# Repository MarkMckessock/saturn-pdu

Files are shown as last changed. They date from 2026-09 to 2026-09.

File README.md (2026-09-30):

# saturn-pdu

**A 1U rack PDU delivering six independently switched and metered 19V outputs,
for a six-node Minisforum MS-01 Kubernetes cluster.**

> **Status: draft specification. Nothing here has been built or bench-verified.**
> Every figure is analytical. Do not fabricate from this repository yet.

Derived from [Shrike-Lab/HomeLab-PDU-V1](https://github.com/Shrike-Lab/HomeLab-PDU-V1).
Licensed **CERN-OHL-S v2** (strongly reciprocal) -- see [`LICENSE`](LICENSE) and
[`NOTICE`](NOTICE).

---

## The problem

Six MS-01 nodes, six 180W bricks, six mains outlets, twelve cables, and no way
to see what any node draws or to power-cycle a wedged one without walking to the
rack.

## What this is

One 1U box: a single mains inlet, six 19V outputs, each switchable over the
network and each reporting volts, amps and watts.

```
IEC inlet ──► RSP-1000-48 ──► 48V bus ─┬──► [2ch board A] ──► ports 1,2
                  ▲                     ├──► [2ch board B] ──► ports 3,4
           remote ON/OFF                └──► [2ch board C] ──► ports 5,6
           (front button)                          │
                                          [control board]
                                          ESP32-S3 + wired Ethernet
                                          6x INA226 telemetry
                                          Prometheus /metrics
```

Each channel is an LM5116 synchronous buck, 48V down to 19V at 7A, with its own
fuse, its own current limit, and its own overvoltage crowbar that works **with
the microcontroller unpowered**.

## Three design rules that explain most of the decisions

1. **Outputs fail ON.** Channels are held on by resistors. The MCU can only turn
   one *off*, by actively pulling a pin down. An MCU that is crashed,
   unprogrammed, unpowered or physically removed leaves every node running.
   No firmware path may ever de-energise an output autonomously.
2. **Protection does not depend on software.** A shorted high-side transistor
   puts 48V on a 19V input and destroys a node. Disabling its controller
   achieves nothing when the transistor is a short, so each output carries an
   SCR crowbar with its own reference, powered from its own output.
3. **The display cannot break anything.** It is a separate device on a UART
   link, not the controller. Unplug it and all six outputs keep running and stay
   controllable over the network. A single tap can never de-energise a node.

## Honest cost comparison

About **$750-830** in parts, realistically **$900-1,100** for a first unit once
you budget the three board spins a first high-current layout needs. Six stock
bricks are $240-360.

A used switched-and-metered rack PDU (APC AP7921 class, $150-300) plugged into
your existing bricks gives you remote switching and per-outlet metering this
afternoon. **What this project buys over that is the 1U consolidation and the
elimination of six bricks -- a space and elegance goal, not a functional one.**
That is a fine reason to build it. It should just be the actual reason.

## Safety

**Read [`docs/safety.md`](docs/safety.md) before building or operating.**

The short version: the 19V outputs cannot shock you (IEC 62368-1 ES1), but a
live barrel plug dropped on a rack rail will melt itself. Unused ports stay off;
switch a port off before unplugging it. The mains side inside the chassis *can*
kill you -- unplug at the wall before opening the lid, and wait a minute.

## Repository layout

| Path | Contents |
|---|---|
| `params.yaml` | **Single source of truth.** Every dimension, rating and threshold used in more than one place. Docs, firmware and CAD all read from it |
| `docs/` | Specification, power budget, thermal, protection/FMEA, safety, upstream analysis, deviation log |
| `hardware/kicad/` | KiCad projects: 2-channel power board, control board, backplane |
| `cad/` | Parametric FreeCAD Python, plus STEP/STL exports |
| `firmware/` | ESPHome configuration for the control board and the display |
| `fab/` | Gerbers, BOM, pick-and-place |
| `reference/upstream-19in/` | Upstream's 19" B-rep solids, kept as dimensional reference |

## Build order

Stage-gated. **Do not order the full board set before stage 4 passes.**

| # | Stage | Gate |
|---|---|---|
| 0 | Measure the barrel jack and the real six-node draw | Both recorded |
| 1-2 | Schematics, BOM and sourcing | No unsourceable parts |
| 3 | LM5116 evaluation board, built and measured | A known-good reference exists |
| 4 | One 2-channel board: bring-up, fault injection, 72h burn-in, fault injection **again** | **Hard gate** |
| 5-6 | Control board, firmware, display, chassis | Fail-ON verified by pulling the MCU |
| 7 | **30-day canary on one worker node** | **Hard gate.** Any event resets to day zero |
| 8 | Remaining five nodes; control-plane nodes last | 24h six-node soak |

Full detail in [`docs/SPECIFICATION.md`](docs/SPECIFICATION.md) sections 8 and 9.

## Open items

Two measurements and one accepted risk. Both measurements carry provisional
values in `params.yaml` and neither blocks design work.

| ID | Item | Why it does not block |
|---|---|---|
| OPEN-5 | Barrel jack dimensions | Both candidate sizes share the same 8mm panel thread, so the panel cutout is identical. Only the part number is provisional |
| OPEN-6 | Real six-node peak draw | **Downgraded to informational.** The fitted RSP-1000-48 absorbs a reading 38% above estimate, so this validates the power budget rather than gating a purchase |
| R-0 | No independent design review | **Accepted, not resolved.** Bench testing and the 30-day canary stand in for it. Residual risk is moderate and knowingly taken |

## Contributing

This is a personal homelab project, not a product. Issues and observations are
welcome -- particularly from anyone with power-electronics experience, given
R-0. Pull requests are not expected.

Derivatives must remain under CERN-OHL-S v2 and must publish editable source,
not only exports. Upstream's source is in its git history; this repository keeps it in the tree.

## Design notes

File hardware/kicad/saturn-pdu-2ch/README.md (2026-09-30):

# saturn-pdu-2ch — 2-channel power board

Open `saturn-pdu-2ch.kicad_pro` in KiCad 10.

| File | What it is | Made by |
|---|---|---|
| `saturn-pdu-2ch.kicad_sch`, `channel.kicad_sch` | Schematic. Top sheet + one channel sheet used twice (CH1, CH2) | `tools/gen_2ch_sch.py` (WP-4b) |
| `saturn-pdu-2ch.kicad_pcb` | Board: outline, holes, stackup, rules, every part loaded and linked | `tools/setup_2ch_pcb.py` (WP-4c) |
| `saturn-pdu-2ch.kicad_dru` | Custom design rules (48 V spacing, switch-node keep-away) | `tools/setup_2ch_pcb.py` |

**Both generator scripts are one-shot.** They overwrite their output. After any hand
edit, change the board from the schematic with *Tools → Update PCB from Schematic*
(F8), never by re-running a script.

## State at the end of WP-4c

- ERC: 0 errors, 0 warnings.
- DRC with schematic parity: **0 parity issues, no errors other than unrouted
  connections.** The remaining warnings are silkscreen labels overlapping each other,
  which go away as parts are spread out.
- Board: 90 × 130 mm, 2 mm corner radius (upstream's outline), 4 × M3 holes 4 mm in from
  each corner.
- Stackup: 4 layers, 2 oz outer / 1 oz inner, 1.62 mm, ENIG. The dielectric split is
  nominal — swap in the fab's own 2 oz stackup when ordering.
- In1.Cu has a full GND plane (press **B** to fill it). In2.Cu is free.

### Net classes

| Class | Nets | Track | Clearance |
|---|---|---|---|
| HV | +48V, VIN_F, SW, HB, HO, HO_G, SNUB | 1.0 mm | 0.2 mm (0.5 mm to non-HV copper, except pad-to-pad inside a part) |
| POWER | VOUT_REG, VOUT1/2, ISNS, GND | 2.0 mm | 0.2 mm |
| GATE | LO, LO_G | 0.5 mm | 0.2 mm |
| Default | everything else | 0.2 mm | 0.2 mm |

The track widths are only defaults. **Carry the 7 A paths in copper pours, not tracks.**

## Placement is a starting point, not a layout

Parts are packed in two columns, one per channel. Power flows from top (J1, 48 V in) to
bottom (J2, 19 V out). Each channel is a KiCad group, so it moves as one.

The order inside a column is roughly right, but the spacing is not. Do the layout
(WP-4d) with **TI's LM5116 EVM layout open beside it** (R-0 control 1). Put every place
you depart from it in `docs/deviations.md`.

## Layout checklist, most important first

1. **Hot loop as small as possible.** Input ceramics (C103–C106) → high-side FET (Q101) →
   low-side FET (Q102) → sense resistor (R103) → back to the ceramics' ground. Keep them
   side by side on the top layer, with the In1 GND plane directly underneath. This loop's
   size sets the switch-node spike, and the D-10 bench gate requires that spike to stay
   at or below 54 V.
2. **Keep the switch node (SW) small.** It only needs to join the FETs and L101. Don't
   pour extra copper on it. Keep it away from FB, CS, OVP_REF and I²C (a DRC rule
   enforces 1 mm).
3. **Kelvin sense.** CS and CSG are 0 Ω links (R104, R105). Route them as a close pair
   straight to R103's pads, not onto the power copper. Do the same for the INA226 inputs
   (VOUT_REG and VOUT) at R118's pads.
4. **Gate drive.** Run HO next to SW and LO next to GND, both short, from U101 to the
   FETs.
5. **Analog ground.** The LM5116 exposed pad is the star point. Place the FB divider
   (R112/R113), the compensation parts (R114, C118, C119) and the RT, SS, RAMP and VCC
   parts next to U101, grounded to its pad area rather than to the power path.
6. **Heat.** Put a thermal-via array under both FETs, into the In1 plane. The inductor,
   R103, R118 and R119 all need copper to spread heat into.
7. **Crowbar.** The SCR (Q105) goes near J2, across VOUT with short, wide copper. The
   OVP divider (R120/R121) senses at the output, not at the inductor.
8. **Snubber (R106/C108, not fitted).** Place it hard across Q102's drain and source so
   it works if it is ever needed.
9. **Connectors.** Pour +48V from J1 to both fuses. Run each VOUT to J2 pins as a pour
   and use both pins.

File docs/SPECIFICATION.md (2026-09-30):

# Saturn PDU — Design Specification v0.1 (DRAFT, pre-review)

**Project:** 1U rack PDU delivering six independently switched and metered 19V outputs
for a six-node Minisforum MS-01 Kubernetes cluster.
**Derived from:** [Shrike-Lab/HomeLab-PDU-V1](https://github.com/Shrike-Lab/HomeLab-PDU-V1) (CERN-OHL-S v2)
**Status:** Draft for review. **Nothing here has been built or bench-verified.**
All calculations are analytical and must be confirmed against manufacturer datasheets
and on hardware before fabrication. Sections marked **[OPEN]** are unresolved.

---

## 1. Context and scope

### 1.1 Problem

Six MS-01 nodes each ship with a 180W 19V external brick. That is six bricks, six mains
outlets, twelve cables and no visibility into per-node power. There is no way to power
cycle a wedged node without physical access to the rack.

### 1.2 Goal

One 1U unit: single mains inlet, six 19V outputs, each independently switchable over the
network and each metered for voltage, current and power.

### 1.3 Out of scope

- Mains-side redundancy, UPS or ATS functions
- Genuine N+1 output redundancy (see §4.2.4 — explicitly rejected)
- Powering anything other than 19V DC loads
- Prometheus/Grafana/Gatus integration on the Saturn side (follow-on, §10)

### 1.4 Relationship to upstream

Upstream is a 5× 65W USB-C PD distribution board fed from a 300W/24V supply. Two facts
determine how much can be inherited:

1. **The load is incompatible.** The MS-01 takes 19V via a barrel jack and
   [cannot be powered over USB-C](https://www.galaxus.at/en/s1/questionandanswer/hello-can-the-mini-pc-also-be-supplied-with-power-via-usb-c-or-is-it-only-possible-with-the-mains-ad-782803);
   Minisforum support confirms the barrel jack is required. Every USB-C PD module, the
   PD-specific board and the 24V rail are discarded.
2. **Upstream's editable source exists only in its git history.** _Corrected at WP-4c:_
   the original census checked only the current tree and wrongly concluded the originals
   were withheld. The KiCad project and SolidWorks parts were committed in December 2025
   and removed from the tree in February 2026; they remain in history under CERN-OHL-S
   (docs/upstream-analysis.md §1).

This is therefore a **new design that inherits upstream's mechanical architecture and
protection patterns**, not a modification of upstream's electronics. See §2.

---

## 2. Upstream analysis (reverse-engineered from fab files)

### 2.1 What was extracted

| Property | Value | Source |
|---|---|---|
| Board outline | **90 × 130 mm** (X 51.8→141.8, Y −38.3→−168.3) | `Edge_Cuts.gm1` |
| Stackup | 2-layer, 1.6mm, 2oz | README; confirmed by pour-heavy layout |
| Trace apertures | 0.8 / 1.0 / **2.0 mm max** | `F_Cu.gtl` aperture list |
| Copper pours | 17 regions top, 1 bottom (GND plane) | `G36` region count |
| Drills | 0.6 / 0.75 / 1.0 / 1.8 / 3.2 mm PTH; 3.0 mm NPTH ×4 — **connector pegs, not mounting holes** (corrected at WP-4c) | `.drl` tool tables |

### 2.2 Reconstructed topology

Through-hole connectivity is fully recoverable from `HomeLab-PSU-V1_netlist.ipc`:

```
J1 (Molex Mini-Fit Jr) +24V ─► F1 15A ─► Q1 high-side P-FET ─► +24V_SWITCHED
                                          ▲ gate: R4 100k, D7 12V zener,
                                            R2 47k, R3 100R, latched from J2 button
        D6 SMCJ26A bulk TVS, C1/C2 470µF
                                             │
        ┌────────────┬────────────┬──────────┴─┬────────────┐
     F2 3A        F3 3A        F4 3A        F5 3A        F6 3A
        │            │            │            │            │
     J3/J8       J4/J9      J5/J10      J6/J11      J7/J12    ◄── XPM52C PD modules
     + D1–D5 SMBJ26A TVS, C5–C9 470µF, C10–C14 1µF, C15–C19 100nF
                                             │
                              J13 ─► buck module ─► J15/J16 ─► J17/J18 fan headers
```

**Upstream's board performs no power conversion.** It is a passive fan-out: one master
switch, fusing, TVS clamping, bulk capacitance, and headers for five purchased PD modules
and one purchased buck module. This design inverts that — conversion *is* the board.

### 2.3 Inheritance decisions

| Element | Decision | Justification |
|---|---|---|
| Fuse + TVS + bulk cap per channel | **Inherit**, rescaled | Sound pattern; 3A→5A input fuse, TVS standoff 26V→58V (bus) / 24V (output) |
| Master switch via latching button | **Inherit concept, change implementation** | Use the PSU's remote ON/OFF rather than commutating 15A of 48V through a FET — an option upstream did not have with the HRP-300 |
| Fan rail from switched main rail | **Inherit**, add MCU PWM | Upstream tunes RPM by trimming a buck's output voltage; open-loop and crude |
| ~~4× 3.0mm NPTH mounting pattern~~ | **None exists** | Those holes are Mini-Fit Jr pegs. Power boards use 4× M3, 4 mm from each corner |
| 90×130mm board footprint | **Reference only** | Useful sanity check that a 2-channel board fits the tray |
| Power path, PD modules, 24V rail | **Discard** | Incompatible with the load |
| 2-layer / 2oz / 15A | **Discard** | Under-specified for 800W class |

### 2.4 Defect found in upstream — do not inherit

`Q1` is `NCEP40PT15D` (N-channel, 40V) in the README BOM but `IRF9540NPBF`
(**P-channel**, 100V) in the JLCPCB `bom.csv` LCSC field. These are opposite polarity and
not interchangeable. The gate network (100k pull-up, 12V zener clamp, pulled low to turn
on) is unambiguously a **P-channel** high-side switch, so the CSV is correct and the
README is wrong. Building from the README alone yields a non-functioning board.

### 2.5 What could not be extracted

- **The schematic PDFs contain no machine-readable text.** Both are ~34KB with no
  embedded fonts and no `Tj`/`TJ` operators — KiCad plotted every label as vector
  strokes. No net names, designators or values are programmatically recoverable.
  Rendering them for human review requires `brew install poppler`.
- **The IPC-356 netlist covers through-hole pads only.** SMD connectivity is absent, so
  the exact wiring of the Q1 gate network is **inferred from part values and standard
  practice, not extracted**. It is almost certainly the textbook arrangement, but this
  is an inference and is labelled as such.

Neither gap is material, because the power path is not being copied.

---

## 3. Requirements

Priority: **M** mandatory · **S** should · **C** could.

### 3.1 Functional

| ID | Pri | Requirement | Justification |
|---|---|---|---|
| F-1 | M | Six independent 19V DC outputs, each on a panel-mount barrel jack | Matches stock MS-01 input; no node-side modification |
| F-2 | M | Each output independently switchable on/off over the network | Primary purpose: recover a wedged node without rack access |
| F-3 | M | Each output reports voltage, current and power | Sizing evidence (§4.2.3) and per-node cost attribution |
| F-4 | M | Master power control via front-panel latching button | Local override; inherited from upstream |
| F-5 | M | Outputs default to ON at power-up without network or MCU | A PDU that needs a working control plane to deliver power is a liability |
| F-6 | S | Per-output status indication on the front panel | At-a-glance diagnosis at the rack |
| F-7 | C | Per-output soft-start sequencing/stagger at power-on | Reduces aggregate inrush; not required if per-channel soft-start suffices |
| F-8 | S | **Front-panel colour display showing live aggregate and per-node power draw** | Answers "what is this cluster drawing right now" without a laptop or a network |
| F-9 | M | **The display must not be able to switch a node off in a single touch, and its failure must not affect power delivery** | It is a rack front panel — cables and hands brush past it. A one-tap node shutdown is an accidental-outage machine |

### 3.2 Electrical

| ID | Pri | Requirement | Justification |
|---|---|---|---|
| E-1 | M | Output 19.0V ±2% from no load to rated load | MS-01 spec is 19V; laptop-style inputs tolerate ±5% |
| E-2 | M | ≥7A continuous per output (133W) | Covers measured sustained (95W) and turbo (115W) with margin |
| E-3 | M | Output ripple ≤200 mVpp at rated load | ~1% of 19V; conservative for a DC input stage |
| E-4 | M | Aggregate continuous output ≥690W | Six nodes at measured turbo (§4.2.1) |
| E-5 | M | Universal AC input 100–240V, 50/60Hz, active PFC | Mains-agnostic; PFC required at this power |
| E-6 | S | Conversion efficiency ≥94% per channel at 7A | Sets the thermal budget (§4.7) |
| E-7 | M | Load-step 0→7A without exceeding E-1 bounds beyond transient recovery | Nodes step load hard on turbo entry |

### 3.3 Protection and safety

| ID | Pri | Requirement | Justification |
|---|---|---|---|
| P-1 | M | **Per-output OVP that operates with the MCU unpowered** | A shorted high-side FET puts 48V on a 19V input. This is the one failure mode that destroys nodes; it must not depend on firmware |
| P-2 | M | OVP must protect the load even if the pass device is shorted | Disabling a controller does nothing when its FET is a short — requires a crowbar (§4.4.2) |
| P-3 | M | Per-channel input fusing, coordinated with the crowbar | Isolates a failed channel; the crowbar holds the output down until it clears |
| P-4 | M | Per-channel cycle-by-cycle current limit | Handles output short and node fault without fuse operation |
| P-5 | M | Mains fusing at the IEC inlet | Standard practice; inherited from upstream |
| P-6 | M | Bus-level fusing on the 48V rail | Protects wiring and PSU against a backplane fault |
| P-7 | M | TVS on the 48V bus and on each 19V output | Transient clamping |
| P-8 | M | Controlled soft-start into the MS-01's input capacitance | Prevents inrush-induced fuse operation and rail sag |
| P-9 | M | Output bleed so a commanded power cycle actually discharges | An output that coasts at 15V is not a power cycle |
| P-10 | M | Thermal monitoring per board with automatic shutdown | Last-resort protection against fan failure or blocked airflow |
| P-11 | M | No user-accessible mains voltage with the lid fitted | Basic electrical safety |
| P-12 | S | Alert when a port is energised but drawing no current | An enabled port at 19V drawing <20mA has nothing plugged in — a live barrel plug is loose in the rack. **Alert only; it must never switch the port off** (see S-4) |

### 3.4 Mechanical

| ID | Pri | Requirement | Justification |
|---|---|---|---|
| M-1 | M | 19" rack, 1U (≤44.45mm), standard ear spacing | Target rack |
| M-2 | M | Chassis accepts the RSP-1000-48 (295 × 127 × 41mm) | Fitted unit as of WP-3. The envelope is unchanged from when this was written as an upgrade path — which is why the switch cost nothing (§4.2.3) |
| M-3 | M | All six barrel jacks, IEC inlet and RJ45 on the rear panel | Cables exit rearward in a rack |
| ~~M-7~~ | — | ~~Output jacks accept a **locking** (threaded-collar) barrel plug~~ | **WITHDRAWN 2026-09-30.** No locking jack exists above 5A in this barrel size (WP-3), and the requirement was dropped by decision. `docs/safety.md` §2 records what the remaining controls are and that they are thinner for it |
| M-4 | M | Master button and status indication on the front panel | Operated from the front |
| M-5 | S | 3D-printed panels fit a 220×220mm bed | Inherited from upstream; keeps the design home-printable |
| M-6 | M | Board-mounted components ≤40mm tall | 41mm PSU in a 43mm envelope — height is the binding axis |

### 3.5 Thermal and acoustic

| ID | Pri | Requirement | Justification |
|---|---|---|---|
| T-1 | M | Sustain rated output at 35°C ambient without thermal throttle | Realistic rack inlet temperature |
| T-2 | M | No component above 80% of its rated maximum temperature at rated load | Derating for service life |
| T-3 | S | ≤35 dBA at cluster idle | It lives in a homelab, not a datacentre |
| T-4 | M | Fan speed driven by measured board temperature | Quiet at idle, adequate under load |
| T-5 | M | Fan failure detected and reported | Tach feedback; silent fan failure precedes thermal failure |

### 3.6 Control and software

| ID | Pri | Requirement | Justification |
|---|---|---|---|
| S-1 | M | Wired Ethernet, not WiFi | A PDU you cannot reach is worthless; it sits in a rack next to a switch |
| S-2 | M | Per-port on/off/cycle over HTTP | Scriptable recovery |
| S-3 | M | Prometheus-compatible metrics endpoint | Saturn already runs Prometheus |
| S-4 | M | **Loss of network, MCU crash or firmware failure must not drop output power** | Restates F-5 from the software side; the watchdog must never disable outputs |
| S-5 | S | OTA firmware update | It will be inside a closed chassis in a rack |
| S-6 | S | Report PSU health if the PSU exposes a DC-OK signal | Early warning |
| S-7 | C | MQTT publication | Convenience for home automation |

### 3.7 Licensing and documentation

| ID | Pri | Requirement | Justification |
|---|---|---|---|
| L-1 | M | Licensed CERN-OHL-S v2 | Upstream is strongly reciprocal; not optional |
| L-2 | M | Modifications documented relative to upstream | CERN-OHL-S §3.3 |
| L-3 | M | **Publish editable source** (KiCad projects, FreeCAD models), not only exports | The licence requires the preferred form for modification — upstream keeps it only in git history; this derivative keeps it in the tree |
| L-4 | M | ShrikeLab name and logo not carried into this derivative | CERN-OHL-S §7 grants no trademark rights |

---

## 4. Design

### 4.1 System architecture

```
IEC inlet (fused) ──► RSP-1000-48 ──► 48V bus (fused) ──► backplane
                        ▲                                    │
                remote ON/OFF                                 │
                from latching button                          │
                        ┌───────────────────────┬─────────────┴─────────┐
                   [2ch board A]           [2ch board B]           [2ch board C]
                    ch1    ch2              ch3    ch4              ch5    ch6
                        │                       │                       │
   per channel: 5A fuse ─► LM5116 sync buck 48V→19V/7A ─► 2mΩ shunt ─► TVS ─► barrel jack
                           + independent OVP comparator ─► crowbar SCR
                        │                       │                       │
                   [control board]  ESP32-S3 + W5500
                      ├─ I²C  → 6× INA226        V / A / W per node
                      ├─ GPIO → 6× LM5116 UVLO   per-node enable (open-drain, fail-ON)
                      ├─ PWM  → 3× NF-A4x20 + tach, NTC-driven
                      └─ front panel: latching button, 6 status LEDs
```

### 4.2 Power budget and PSU selection

#### 4.2.1 Load characterisation

MS-01 nameplate is 19V/9.47A/180W (Huntkey HKA18019095-6C). Measured behaviour differs
sharply and is what the design is sized against:

| Condition | Per node | ×6 | Source |
|---|---|---|---|
| Idle, tuned Linux | ~13W | 78W | cloudmagazin |
| Idle, Windows | 25–30W | 180W | ServeTheHome |
| Sustained load | 90–95W | 570W | ServeTheHome |
| Turbo, first ~45s | ~115W | 690W | ServeTheHome |
| Nameplate | 180W | 1080W | Minisforum |

**Design point: 690W aggregate** (all six in turbo). Sizing to the 1080W nameplate would
be sizing to a number no measurement supports.

#### 4.2.2 Rail loading

At 95% channel efficiency, 690W delivered draws **726W** from the 48V rail — **72% of
the RSP-1000-48's 1008W.** Sustained all-six load draws 600W (60%).

This is comfortable, and it was not always so. See §4.2.3.

#### 4.2.3 Selection

**Mean Well RSP-1000-48** — 48V, 21A, 1008W, 295 × 127 × 41 mm, ~91%, active PFC,
built-in fan, remote sense, remote ON/OFF, DC OK, 1U profile.

**This is a change from the RSP-1000-48 specified in earlier drafts, made at WP-3 when
sourcing revealed the RSP-1000-48 is discontinued.** The reasoning is recorded because
the change closes a risk rather than merely substituting a part:

| | RSP-1000-48 (was) | **RSP-1000-48 (is)** | UHP-750-48 (considered) |
|---|---|---|---|
| Lifecycle | **Discontinued** | **Active** | Active |
| Availability | ~700 units remain | In stock | **17-week lead** |
| Output | 753.6W | **1008W** | 753.6W |
| Load at the 726W peak | **96%** | **72%** | 96% |
| Efficiency | 92% | ~91% | **95%** |
| Cooling | Own fan | Own fan | **Fanless — its ~38W becomes the chassis's problem** |
| Size | 250 × 127 × 41 | 295 × 127 × 41 | 237 × 100 × 41 |
| Price | $186–237 | ~$230–260 | ~$194 |

**Three consequences, all favourable:**

1. **The chassis does not change.** It was already dimensioned to the 295mm RSP-1000-48
   under M-2, precisely so this unit would drop in. The upgrade path became the build.
2. **Risk R-3 closes outright.** 72% of rating is not a marginal operating point, so the
   headroom question that motivated M-2 no longer exists.
3. **OPEN-6 is downgraded from a hard gate to informational.** The six-node measurement
   was a gate because a high reading would have invalidated a 753.6W supply. At 1008W the
   design tolerates a measurement 38% above the estimate before the question reopens.
   The measurement is still worth taking — it is still the only real evidence in §4.2.1 —
   but it no longer blocks a purchase.

**The UHP-750-48 was the interesting near-miss.** It is Mean Well's actual successor and
is better on two axes that matter here: 95% efficiency, and **completely silent**, which
would have helped T-3 more than anything else in the design, since the PSU's own fan is
likely the loudest thing in the box. It was rejected on a 17-week lead time and because
being fanless inverts the thermal budget — its ~38W of loss stops being self-managed and
becomes chassis dissipation, roughly doubling the airflow the design must handle (§4.7).
Worth revisiting for a second unit, where a four-month lead is not an obstacle.

**Mount the PSU with its long axis across the rack width.** At 295mm of the 438.7mm
internal width it consumes only 127mm of depth, so upstream's `19in_Dual-Tray` depth of
~213mm suffices. Remaining volume: a full-width **438.7 × 86 mm** band (37,728 mm²) plus
a **143.7 × 127 mm** pocket beside the PSU — ample for three 2-channel boards, the control
board and the backplane. **Height, not depth, is the binding constraint** (M-6).

#### 4.2.4 Decision record: single large supply vs 2× 450W

Analysed and rejected. Recorded so it is not re-litigated.

> Originally argued against the 753.6W RSP-750-48, where the dual option's headroom
> advantage was its strongest card. **With the RSP-1000-48 fitted (§4.2.3) the single
> supply now wins on headroom too**, so the argument below only got stronger. It is
> preserved because the three structural objections are what actually decided it, and
> they are unchanged.

| | 1× RSP-1000-48 | 2× HRP-450-48 |
|---|---|---|
| Total | **1008W** | 912W |
| Load at 726W peak | **72%** | 80% |
| Efficiency | 92% | 89.5% (~22W more heat in 1U) |
| Footprint | 250×127 = 31,750 mm² | rotated 210×218 = 45,780 mm² |
| Side-by-side fit | n/a | **2×218 = 436mm in 438.7mm — does not fit** |
| AC inlets | 1 | 2 |
| Board architecture | 3× identical 2-channel | forced to 2× 3-channel |

Dual no longer wins on headroom at all — 1008W beats 912W, and 72% beats 80%. When this
was written against the 753.6W unit it did, and that was the strongest argument for it.
It lost then on three structural counts, all of which still stand:

1. **It cannot sit side-by-side.** 1.35mm per side is inside sheet-metal tolerance,
   before airflow or cable routing. Only a 90° rotation works, costing 44% more tray area.
2. **It forces two independent 48V domains.** HRP-450s have no active current sharing and
   cannot be paralleled. Two domains must not share a board's input, so the 3× identical
   2-channel architecture collapses into 2× 3-channel.
3. **Its resilience benefit is partitioning, not redundancy.** 456W cannot carry six nodes
   at 690W, so a PSU failure drops three nodes rather than failing over. With three
   control-plane nodes split 2+1, half of all PSU failures lose quorum anyway. The
   backplane, master switch and chassis fan remain single points of failure regardless.

The headroom concern was answered by fitting the RSP-1000-48 outright (§4.2.3), which also supports
active current sharing if a second chassis is ever wanted. Genuine cluster resilience
belongs at the second-PDU level, not inside one 1U box.

### 4.3 Buck channel design

#### 4.3.1 Controller selection

**TI LM5116** — 6–100V input, current-mode synchronous buck controller, external N-FETs.
TI characterises it as *"most efficient for output currents of 2A to 10A"* with discrete
SO-8 MOSFETs; 7A sits mid-range. Current-mode control simplifies compensation relative to
the voltage-mode LM5146.

#### 4.3.1.1 OPEN-1 / R-7 — RESOLVED: the integrated-FET route is not thermally viable

R-0 and R-2 both argued for an integrated-FET regulator to cut layout risk. That option
was investigated properly and **fails on thermals.** The reasoning is recorded because the
conclusion is load-bearing.

**Candidates.** Only one part in the 60V-class integrated family reaches a 48V bus:

| Part | V_in max | I_out | Verdict |
|---|---|---|---|
| LT8645S | 65V | 8A | Voltage range OK, **thermals fail** — see below |
| LT8648S / LT8648SP | **42V** | 15A | **Excluded** — below a 48V bus |
| LT8641 | 65V | 3.5A | Insufficient current |

**Output voltage was not the obstacle.** The LT8645S range is 0.97V to (V_in − 0.5V), so
19V from 48V is comfortably inside it. This was the stated concern in R-7 and it is wrong.

**Package dissipation is the obstacle.** The datasheet gives **θ_JA = 31°C/W**,
θ_JC(pad) = 6°C/W, T_J(max) = 125°C. At 133W output:

| Assumed efficiency | P_diss | T_J at 35°C ambient (θ_JA = 31) |
|---|---|---|
| 95% | 7.0W | **252°C** |
| 96% | 5.5W | **207°C** |
| 96%, generous θ_JA = 15°C/W (heavy copper) | 5.5W | **118°C — no margin** |

Even the most favourable case sits on the 125°C limit, and it requires simultaneously
assuming best-case efficiency *and* a θ_JA half the datasheet figure. **There is no
operating point with usable margin.**

**Why.** The 8A rating is real, but it is a rating at low output *power*. At 5V/8A the
part delivers 40W and dissipates ~3W. Here it would deliver 133W. Conduction losses scale
with I² regardless of V_out, and all of it lands in one 4 × 7 mm package.

**The discrete route wins precisely because it is discrete.** Two SO-8 FETs each carry
their own losses into their own thermal pad, with the inductor's ~0.7W in a third package.
The dominant single-component load is the high-side FET at ~1.84W (§4.3.3); at a
pour-assisted θ_JA of ~35°C/W that is a 64°C rise, so T_J ≈ 99°C at 35°C ambient with
forced air still to come. Spreading the heat is not a side benefit here — it is the
requirement.

**Decision: LM5116 + discrete MOSFETs. Confirmed, not defaulted.**

> **This closes OPEN-1 and R-7, and it escalates R-0.** The layout-risk mitigation that
> integrated FETs would have provided is unavailable. **Independent schematic and layout
> review is therefore mandatory, not advisory.**

#### 4.3.2 Operating point

| Parameter | Value | Derivation |
|---|---|---|
| V_in | 48V | Rail |
| V_out | 19.0V | MS-01 spec |
| I_out | 7A continuous (133W) | E-2 |
| Duty cycle D | 0.396 ideal, ~0.41 with losses | V_out/V_in |
| f_sw | **250 kHz** | See §4.3.3 — trades switching loss against inductor size |
| Ripple ΔI_L | 30% of I_out = 2.1A target | Standard practice |

**Inductor:** `L = V_out(1−D) / (f_sw · ΔI_L) = 19 × 0.604 / (250k × 2.1) = 21.9 µH` → **22 µH standard**.
At 22µH and 250kHz, actual `ΔI_L = 19 × 0.604 / (250k × 22µ) = 2.09A`, so `I_pk = 7 + 1.04 = 8.04A`.

#### 4.3.2.1 OPEN-2 — RESOLVED: Coilcraft XAL1510-223

The first-draft part (Bourns SRP1265A-220M) was rated **9A** against an 8.04A peak — 12%
margin, and saturation derates with temperature. Rejected. Sourced replacements:

| Part | L | I_sat | DCR typ | Size | Verdict |
|---|---|---|---|---|---|
| **Coilcraft XAL1510-223** | 22µH | **18.7A** | 14.5mΩ | 15.5×16.5×10mm | **Selected** |
| Coilcraft XAL1510-153 | 15µH | 23.0A | 9.2mΩ | same | Alternate, see below |
| Würth 74439370220 | 22µH | 22.4A (30% drop) | — | 15.4×16.4×10mm | Viable second source |
| Bourns SRP1265A-220M | 22µH | 9.0A | 12mΩ | — | **Rejected** |

**XAL1510-223 selected.** 18.7A saturation against an 8.04A peak is **2.3× margin**, which
survives thermal derating and fault transients without argument. It holds the designed 30%
ripple, and at 10mm tall it is untroubled by the 1U envelope.

**Cost of the choice:** DCR is 14.5mΩ, not the ≤8mΩ originally targeted. Conduction loss
rises from 0.39W to **0.71W** per channel — 0.32W × 6 = ~1.9W more heat in the chassis.
Accepted; saturation margin is worth more than 2W of fan duty.

**XAL1510-153 (15µH) is the alternate**, and is better on paper — 23A I_sat and 9.2mΩ DCR,
so 0.45W instead of 0.71W. It is not the primary because at 15µH the ripple rises to 3.06A
(44%), above the 20–40% band, which increases output-capacitor RMS current and core loss.
**Revisit it if the thermal measurement at stage 3 shows the 22µH part's DCR loss is the
binding constraint** — that is a measurement, not a guess, and the parts are pin-compatible.

#### 4.3.3 Loss budget (per channel at 7A)

Assuming 60V / ~2.7mΩ logic-level MOSFETs (**Infineon BSC0702LS**, fitted at WP-3),
R_ds(on) hot ≈ 1.5× the 4.5V maximum = 5.85mΩ — deliberately the pessimistic end, because
the LM5116 drives its gates from a 7.4V rail rather than 10V:

> **Corrected at WP-3.** This section originally named `PSMN5R2-60YS`. **No such part
> exists** — the real Nexperia device is `PSMN5R5-60YS` (5.2mΩ), and it is out of stock.
> The substituted BSC0702LS is lower R_ds(on), lower Q_g, cheaper, in four-figure stock,
> and — the reason that actually matters — **characterised at V_gs = 4.5V as well as 10V**,
> so its worst case at the LM5116's 7.4V drive is bounded rather than estimated. Recorded
> as D-8; full comparison in `fab/sourcing-notes.md` §1.1.
>
> **Superseded at WP-4b (D-10).** The BSC0702LS's gate charge (~68nC per HS+LS pair at
> 7.4V) draws ~17mA from the LM5116's VCC regulator at 250kHz, above its guaranteed 15mA
> — start-up would not be guaranteed. Replaced by **TI CSD18563Q5A** (≤20nC each, ~7.5mA
> per pair). The conduction figures below were computed for the BSC0702LS; with the
> CSD18563Q5A they rise by ~0.3W per channel, while switching loss — still the dominant
> term — falls.

| Loss | Value | Derivation |
|---|---|---|
| HS conduction | 0.12W | `I² · R_ds · D = 49 × 0.00585 × 0.41` |
| LS conduction | 0.17W | `49 × 0.00585 × 0.59` |
| **HS switching** | **1.68W** | `0.5 · V_in · I_out · (t_r+t_f) · f_sw = 0.5 × 48 × 7 × 40n × 250k` |
| Gate drive | 0.08W | `Q_g · V_drv · f_sw × 2`, Q_g 43nC @ 10V |
| Inductor DCR | 0.78W | `49 × 0.016` — the XAL1510-223's **maximum** DCR, not typical |
| Inductor core | ~0.20W | Estimate |
| Current-sense 7mΩ | 0.34W | `49 × 0.007` — requires a 1W part |
| INA226 shunt 2mΩ | 0.10W | `49 × 0.002` |
| Caps ESR, controller I_q, copper | ~0.4W | Estimate |
| **Accounted total** | **~3.9W** | → 97.2% |
| **Design target** | **≤6.6W** | **95%**, with margin for unmodelled loss |

**Switching loss dominates at 48V input** — 1.68W of an accounted 3.9W, in one package.
This drives three decisions: 250kHz rather than 300kHz+; low-Q_g FET selection as a
primary criterion; and it is the strongest technical argument for evaluating the
integrated-FET LT8645S under [OPEN-1].

Design efficiency is held at **95%**, not the 97.2% the accounted losses suggest, because
the model omits layout-dependent losses. 94% is the requirement (E-6).

#### 4.3.4 Component targets

| Item | Specification |
|---|---|
| MOSFETs | ≥60V V_ds, ≤6mΩ R_ds(on), low Q_g, thermally-padded SO-8/PQFN |
| Inductor | 22µH, I_sat ≥12A, I_rms ≥8A, DCR ≤8mΩ, shielded |
| Current sense | 7mΩ, ≥1W, ≤100ppm/°C, 2512 |
| Telemetry shunt | 2mΩ, ≥0.5W, ≤50ppm/°C |
| Output caps | 35V rated, low-ESR polymer + ceramic, ripple per E-3 |
| Input caps | 100V ceramic + 63V bulk |

Current limit set at ~1.5× rated (≈10.5A) via the sense resistor (P-4).

### 4.4 Protection design

#### 4.4.1 Why enable-pin shutdown is insufficient

Per-channel switching is implemented by pulling the LM5116 UVLO pin low (§4.5.2), which
also provides soft-start on every power-on (P-8). **This is adequate for commanded
switching and for controller-detected faults, and inadequate for a shorted high-side
FET** — when the pass device is a short, disabling its controller achieves nothing. P-2
exists because of this, and it drives §4.4.2.

#### 4.4.2 Output OVP — crowbar

Each channel carries an **OVP comparator with its own reference, powered from the
channel's own output**, independent of the MCU and of the regulation loop (P-1).

- **Trip point ~21.5V.** Above 19V + 10% to avoid nuisance trips on load-step overshoot;
  below the ~25V rating typical of a laptop-style DC input stage.
- On trip the comparator fires an **SCR crowbar across the 19V output**, clamping the node
  input to the SCR forward drop (~1.5V) regardless of what the buck stage is doing.
- The crowbar draws fault current through the channel's **5A fast-blow 48V input fuse**
  until it clears, isolating the channel permanently.

**Coordination:** the fault path is 48V → shorted HS FET → inductor → SCR → ground,
current-limited by the PSU (~21A). At ~3× rating a 5A fast-blow clears in the order of
100ms. During that window the node sees the SCR drop, not 48V. The crowbar does the
protecting; the fuse does the isolating. The SCR must be rated for the PSU's limited
current for that duration.

**OPEN-3 — RESOLVED, favourably.** The RSP-1000-48's overload behaviour is specified as
**"over load (constant current limiting)"**. This is the best of the three possible
behaviours for crowbar coordination:

- **Constant current** means that during a crowbar event the PSU *holds* current at its
  limit (21A rated, trimmable to 110%) rather than shutting down or hiccupping. A 5A
  fast-blow fuse seeing a sustained ~21A — 4.2× rating — clears predictably, in the order
  of 10–50ms. **The RSP-1000-48 improved this** over the originally specified RSP-750-48's
  15.7A: more fault current into a fast-blow fuse means a shorter clearing time, so the
  node sits behind the crowbar for less of it. The cost is an SCR that must carry 21A
  rather than 15.7A for that window — a selection criterion, not a problem.
- Had it been **hiccup** mode, the PSU would have pulsed on and off, the fuse would have
  seen an intermittent current with long cooling gaps, and clearing time would have become
  indeterminate — the fuse might never clear while the node sat behind a repeatedly-firing
  crowbar. That failure mode does not arise here.

The unit also carries short circuit, over voltage and over temperature protection, and is
UL 62368-1 / TÜV EN 62368-1 approved.

> **Residual, for the R-0 reviewer:** constant-current limiting is shared across all six
> channels. A crowbar on one channel pulls the *whole bus* to its current limit until that
> channel's fuse clears, so for ~100ms the other five channels see a sagging 48V rail.
> Each buck stage must ride through that without dropping its output — this is why input
> bulk capacitance per channel is specified, and it is a specific item to put in front of
> the reviewer rather than assume.

#### 4.4.3 Protection summary

| Layer | Device | Threshold | Covers |
|---|---|---|---|
| Mains | IEC inlet fuse | Per PSU inrush rating | Mains fault |
| Bus | 48V fuse | 20A | Backplane fault |
| Channel input | 5A fast-blow | 5A | Channel catastrophic failure; crowbar coordination |
| Channel regulation | LM5116 current limit | ~10.5A | Output short, node fault |
| Channel output | **OVP comparator + SCR crowbar** | ~21.5V | **Shorted pass device — the node-destroying mode** |
| Channel output | TVS | ~24V standoff | Transients |
| Bus | TVS | ~58V standoff | Transients |
| Thermal | NTC per board → MCU | Per T-2 | Fan failure, blocked airflow |
| Discharge | Bleed resistor per output | — | P-9 |

### 4.5 Control and telemetry

#### 4.5.1 Metering

**INA226** per channel, high-side on the 19V output, 2mΩ shunt.

- At 7A: 14mV across the shunt, against the INA226's ±81.92mV range — 17% of range, so
  headroom for fault currents while retaining resolution.
- Bus-voltage common mode 19V, against a 36V maximum. Compliant.
- Current LSB ≈ 214µA (7A / 32768). Resolution is far beyond what is needed.
- Six devices on one I²C bus; the INA226's A0/A1 pins give 16 addresses. No multiplexing.

#### 4.5.2 Switching — fail-ON is a requirement, not a default

Each channel's LM5116 UVLO pin is held in the **enabled** state by its own resistor
divider from the 48V rail. The MCU disables a channel by pulling that node low through an
**open-drain** N-FET.

This satisfies F-5 and S-4 directly: an unpowered, crashed, unprogrammed or removed MCU
leaves every output **on**. There is no firmware state in which the PDU drops power it was
not told to drop. **The watchdog must reset the MCU, never disable outputs.**

#### 4.5.3 Master switching

The front-panel latching button drives the **PSU's remote ON/OFF input** rather than
switching 48V through a FET. This avoids commutating ~15A and eliminates upstream's
master-FET entirely — an option upstream did not have with the HRP-300.

**OPEN-4 — RESOLVED.** The RSP-1000-48 has **built-in remote ON/OFF control, a DC OK
signal, remote sense, and a 5V auxiliary output**, all on connector **CN50** (Hirose
DF11-12DP-2DS, 12-pin; the mating DF11-12DS-2C and its crimps are a BOM line).

Remote ON/OFF is a **dry contact between CN50 pin 6 (on/off) and pin 2 (−S)**: shorted
turns the output on, open turns it off. The front-panel latching button does exactly this.
No AC-side relay, no master FET, no 15A commutation anywhere in the design.

> **Note the pinout differs from the RSP-750 series**, which uses pin 13 to pin 14. If you
> have the RSP-750 wiring in your head from an earlier draft of this document, discard it.

**The DC OK signal satisfies S-6** as a plain GPIO input, no extra hardware. Output current
is trimmable 40–110% via an external DC signal — not used in normal operation, but it means
the bus current limit can be *lowered* during bring-up to make early faults gentler (R-0
control 8).

##### The auxiliary rail is not used, and that is deliberate

The RSP-1000-48's aux output is **5V at 0.5A — 2.5W**. Earlier drafts, written against the
RSP-750's 12V aux, planned to run the control board and display from it. That does not work
here, for two independent reasons:

1. **It is too small.** ESP32-S3 (~0.4W) + W5500 (~0.45W) + display with backlight (~0.75W)
   + six INA226s + the LED expander comes to roughly **2.0W of the 2.5W available — 80%**,
   which is the derating limit (T-2), not a margin.
2. **The fans need 12V regardless.** Three NF-A4x20 PWM cannot run from a 5V rail at all.

**Housekeeping therefore comes from the 48V bus**, via a small **LM5164** (100V input, 1A,
integrated FET) producing 12V for the fans, and a second stage producing 5V for the logic.

This is not a compromise — it is better than the original plan. The property the aux rail
was wanted for was *"the MCU stays alive and telemetry keeps reporting even with every
output channel disabled or faulted."* **The 48V bus is live whenever the PSU is on,
independently of whether any channel is enabled**, so it provides exactly that property
with an order of magnitude more current available. The aux rail is brought to a header and
left unpopulated, available as a standby feed if a use for it ever appears.

#### 4.5.4 MCU and connectivity

**Housekeeping supply** (see §4.5.3): 48V bus → LM5164 → 12V/1A → fans; 12V → 5V/1A →
logic. Estimated draw ~2.0W. The control board is therefore alive whenever the PSU is on,
regardless of the state of any output channel.

**ESP32-S3** with **W5500** SPI Ethernet (S-1). GPIO budget: 6 enable + 2 I²C + 4 SPI +
3 fan PWM + 3 tach + 1 button + 3 NTC ADC ≈ 22, plus status LEDs via an I²C expander to
conserve pins. Comfortably within the S-3's ~45 usable GPIO.

#### 4.5.5 Firmware

**ESPHome**, not bare ESP-IDF. Native `ina226`, `switch`, `fan` and NTC components, a
built-in Prometheus endpoint (S-3) and OTA (S-5) reduce this to configuration rather than
a C firmware project — proportionate for six switches and eighteen sensors.

```
GET  /metrics                    saturn_pdu_watts{port="3"} 94.2
POST /switch/port_3/turn_off
```

### 4.5.6 Front-panel display (F-8, F-9)

**1U is the whole problem here.** The panel is 44.45mm tall; after rack ears, folds and
mounting margin roughly **38mm of usable window height** remains. That single number
eliminates most touchscreens before any other consideration:

| Option | Module size | Fits 38mm? | Touch |
|---|---|---|---|
| **LILYGO T-Display-S3 Touch** — 1.9" 170×320 IPS | **60.8 × 25.5 mm** | **Yes, comfortably** | **Capacitive (CST816)** |
| 0.96" OLED SSD1306 | 27 × 27 mm | Yes | No |
| 2.42" OLED SSD1309 | 72 × 42 mm | Marginal | No |
| 2.8" TFT 240×320 | 69 × 50 mm | **No** | Capacitive available |
| 3.5" TFT | 85 × 55 mm | **No** | — |

**Selected: LILYGO T-Display-S3 Touch** — 1.9" 170×320 colour IPS (ST7789) with a CST816
capacitive touch layer, ~$25, and existing ESPHome/LVGL community support. It is the only
option found that is both a genuine colour touchscreen and physically fits 1U. The
landscape 320×170 aspect suits a rack panel well: one wide row per node.

**It runs as a separate device, not as the main controller.** The board carries its own
ESP32-S3, but its display bus consumes ~15 GPIO and the breakout cannot also serve the 22
GPIO the control board needs (§4.5.4). More importantly, **F-9 requires that a hung or
crashed display cannot affect power delivery.** So:

- The **control board** owns all six enable lines, the INA226 bus, the fans and the button.
  It is the only thing that can change a power state.
- The **display board** is a client. It reads telemetry from the control board over UART
  and renders it. If it crashes, hangs, or is unplugged entirely, nothing downstream
  notices. Both are powered from the PSU's 12V auxiliary rail (§4.5.3).

**What it shows** — aggregate watts as the headline figure, then six rows of
per-node V / A / W and on/off state, plus fan RPM and board temperature.

**Touch behaviour, per F-9:** navigation and paging are free. **Power control requires two
deliberate steps** — select a node, then hold a confirm control for 2 seconds, with the
node's name shown. A single tap can never de-energise anything. An idle timeout returns to
the read-only aggregate view.

### 4.6 Board architecture

**3× identical 2-channel boards** on a passive backplane carrying 48V, I²C and enable
lines, plus a separate control board.

Justification: one small board design is prototyped and bench-tested at ~$30/spin before
committing to the full set; a failed channel is a cheap field swap; thermal and layout
problems are contained. **The controllers are not the cost driver — assembly is** (§5),
and three identical boards panelise into a single PCBA setup fee.

The MCU is kept off the high-current boards to isolate its ground reference from the
switching nodes.

**Stackup:** 4-layer, 2oz outer / 1oz inner. Upstream's 2-layer/2oz carried 15A via copper
pours; this design carries 15.1A on the bus and 7A per output with switching nodes present,
so inner planes are needed for the return path and thermal spreading.

### 4.7 Thermal design

At the 690W design point, the buck stages dissipate `690/0.95 − 690 ≈ 36W`, plus ~2W of
control — **~38W inside the chassis**. PSU losses (~60W at 92%) are exhausted by the PSU's
own fan and are not part of this budget.

Airflow for a 15°C rise:
`V = P / (ρ · c_p · ΔT) = 38 / (1.2 × 1005 × 15) = 2.1 L/s ≈ 4.5 CFM`

**3× Noctua NF-A4x20 PWM** (~9.4 CFM free air each). Even heavily derated for static
pressure this is several times the requirement; three are specified for distribution
across the three boards and for T-5 tolerance, not because one is insufficient. Fan speed
is NTC-driven (T-4) with tach feedback (T-5), which also serves T-3 — at cluster idle
(~78–180W) dissipation is under 10W and the fans can sit near minimum.

### 4.8 Mechanical design

- Re-model parametrically in **FreeCAD** and publish the source (L-3). Upstream's 19"
  `.stp` files are retained as dimensional reference — they are true B-rep solids and
  dimensionally trustworthy, unlike the mesh-only printed parts.
- Envelope: 483.2mm across ears, 438.7mm internal, ~43mm height, ~213mm depth.
- **Rear panel:** 6× barrel jacks, IEC inlet (fused), RJ45.
- **Front panel:** latching button, 6 status LEDs.
- Power boards mount on 4× M3 holes, 4 mm in from each corner of the 90 × 130 mm outline (upstream has no mounting holes to inherit — corrected at WP-4c).

**[OPEN-5] The barrel jack size is unverified.** Web sources do not state it reliably;
it is most likely 5.5×2.5mm centre-positive. **Measure a stock MS-01 plug with calipers
before any footprint or panel cutout is drawn.** This gates all mechanical work.

**Jack selected at WP-3: Kycon KLDHCX-8-0202-B**, 8A / 24VDC, 5.5 × 2.5mm, $1.81 at qty 10,
5,196 in stock. 8A against a 6.05A turbo peak is 32% margin; against the ~5A sustained draw
it is 63%.

> **It is a right-angle through-hole part, not a panel jack, and that is not a compromise —
> it is the reason it is rated 8A.** Every *panel-mount* 5.5 × 2.5mm jack in the industry
> tops out at 5.0A, because the rating is set by the termination and a soldered PCB joint
> carries more than a panel jack's solder tags. The consequence is a small 2-layer **output
> board** behind the rear panel carrying all six jacks, with the barrels protruding through
> six clearance holes. The six output TVS diodes move onto it as well — a clamp belongs
> beside the connector it protects, not 150mm of wire away. Added to the BOM as assembly
> `OUT`, ~$20 including the board.

#### 4.8.1 The interconnect cable — and the live-plug question

**Six cables are required and they are not in upstream's BOM or in any earlier
draft of this one.** The stock Huntkey brick's cable is **captive** — the plug end
is permanently attached to the brick — so it cannot be reused. These are new leads
with a **barrel plug at both ends**.

**Specify 18AWG.** At 7A over a 0.5m run (1m of conductor there and back):

| Gauge | Resistance | Drop at 7A | Dissipated in the cable |
|---|---|---|---|
| **18AWG** | ~21 mΩ/m | **0.15V** | **1.0W** |
| 20AWG | ~33 mΩ/m | 0.23V | 1.6W |
| 22AWG | ~53 mΩ/m | 0.37V | 2.6W |

Most cheap DC extension leads are 20–22AWG and rated 3–5A. Specify the gauge; do
not buy on price.

**This consumes part of the E-1 budget.** E-1's ±2% is ±0.38V *measured at the PDU
jack*. An 18AWG lead spends 0.15V of it before the node sees anything, so the
regulator setpoint is trimmed slightly high (**~19.1V**) rather than dead-on 19.0V.
A 22AWG lead would spend almost the entire budget by itself.

**On exposed live plugs.** A cable connected at the PDU but not at a node presents
a live 19V male plug with tip and sleeve ~1mm apart. Two separate questions:

- **Shock hazard: none.** IEC 62368-1 classes DC below 60V as **ES1** — no
  electrical energy hazard. A 19V plug is safe to handle.
- **Short-circuit hazard: real.** Dropped on a rack rail or a screw, it bridges 19V
  through a source good for 10.5A before current limiting — ~200W into a pinhead
  contact. Sparks, a melted plug, a scorch mark, possibly welding itself to what it
  touched.

**This hazard is inherited, not introduced.** Every stock brick already ends in a
live male plug with 9.47A behind it; six bricks means six of them in the rack
today. What the PDU adds is the ability to **de-energise a dangling cable
remotely**, which no brick can do. Controls: the P-12 alert and the operating
procedure in `docs/safety.md` — unused ports stay off, and a port is switched off
before it is unplugged.

> M-7 originally added locking jacks as a third control. **It was withdrawn**, both
> because no locking jack exists above 5A in this barrel size and because the
> requirement was dropped by decision. `docs/safety.md` §2 states plainly that the
> two remaining controls are now the whole of the response.

---

## 5. Cost

Qty-10 distributor pricing, indicative, to be verified against live stock.

**Sourced at WP-3 on 2026-09-30.** Thirteen critical-path lines were looked up live;
`fab/bom.csv` marks which. Commodity passives are catalogue estimates.

**Per channel ≈ $21.30:** inductor $7.55 · FETs ×2 $2.76 · LM5116 $1.88 · INA226 $0.63 ·
output caps $3.40 · input caps $2.35 · sense + shunt $0.85 · OVP + crowbar $0.60 ·
fuse + TVS $0.81 · bleed + passives $0.47.

**The inductor is now the single most expensive part in the channel** — more than the
controller and both MOSFETs together. That is what the 2.3× saturation margin costs, and
it is still the right trade (§4.3.2.1).

| Item | Cost |
|---|---|
| 6 buck channels | $126 |
| 3× 4-layer 2-channel PCBs | $20 |
| Output board — 6× jacks, TVS, PCB (§4.8) | $20 |
| Control board | $31 |
| T-Display-S3 Touch display (F-8) | $25 |
| Backplane + 20A bus fuse | $28 |
| PCBA setup + assembly | $120 |
| **Electronics** | **$370** |
| Mean Well RSP-1000-48 | $268 |
| 3× Noctua NF-A4x20 PWM | $45 |
| IEC inlet, latching button, PSU mating connector | $18 |
| 6× 18AWG interconnect cables (§4.8.1) | $30 |
| Sheet metal, printed panels, fasteners, bus wiring | $135 |
| **Chassis and power** | **$496** |
| **Build cost, one unit** | **$937** |
| LM5116 evaluation board — one-off, R-0 control 2 | $136 |
| **First unit, all in** | **$1,074** |

**Excludes prototype iterations, and R-2 says budget three board spins** — add ~$150–250
and several weeks. A realistic all-in first-unit figure is **$1,200–1,330.**

That is ~$150 above the first-draft estimate, almost entirely the PSU ($268 rather than
$165 — the RSP-750-48 was cheaper before it was discontinued) and the inductor. The
silicon came in *under* estimate: the LM5116 at $1.88 against $5.13, the INA226 at $0.63
against $2.50.

Six stock Minisforum bricks are ~$240–360, so this is 4–5× the thing it replaces. The
delta buys remote per-node power control, per-node telemetry, a front-panel display and
1U consolidation. Worth naming plainly: a used switched-and-metered rack PDU (APC AP7921
class, ~$150–300) plugged into the six existing bricks delivers remote switching and
per-outlet metering for a fraction of this, in an afternoon. **What this project buys over
that is the 1U consolidation and the elimination of six bricks — a space and elegance
goal, not a functional one.** That is a perfectly good reason to build it; it should just
be the actual reason.

---

## 6. Open items

| ID | Item | Status | Outcome |
|---|---|---|---|
| OPEN-1 | LM5116 + discretes vs integrated FETs | ✅ **Closed** | **LM5116 + discretes.** Integrated fails on package thermals (§4.3.1.1) |
| OPEN-2 | Inductor saturation rating | ✅ **Closed** | **Coilcraft XAL1510-223**, I_sat 18.7A = 2.3× margin (§4.3.2.1) |
| OPEN-3 | Crowbar/fuse coordination vs PSU overcurrent | ✅ **Closed** | Constant-current limiting — the favourable case (§4.4.2) |
| OPEN-4 | RSP-1000-48 remote ON/OFF | ✅ **Closed** | Built in, plus DC OK, remote sense and a 12V aux rail (§4.5.3) |
| R-7 | 19V from an integrated regulator | ✅ **Closed** | Voltage was never the issue; thermals were. Merged into OPEN-1 |
| **OPEN-5** | **Barrel jack dimensions** | 🔴 **Open — needs you** | Physical caliper measurement. Gates all mechanical work |
| **OPEN-6** | **Real six-node peak power draw** | 🟡 **Open — informational** | Was a gate against a 753.6W supply. At 1008W the design absorbs a reading 38% above estimate, so this now validates §4.2 rather than blocking it |
| OPEN-8 | Rear-panel output connector | ✅ **Closed** | Locking dropped by decision; **Kycon KLDHCX-8-0202-B**, 8A, 5,196 in stock. Right-angle THT, so it brings a small output board with it (§4.8) |
| **R-0** | **Independent schematic + layout review** | 🔴 **Accepted, not resolved** | Declined. Compensating controls in §7 carry the full weight (§4.3.1.1) |
| OPEN-7 | PSU discontinued | ✅ **Closed** | RSP-1000-48 EOL → **RSP-1000-48**, which also closes R-3 (§4.2.3) |

**Everything that could be closed from datasheets has been closed.** The three remaining
items are a physical measurement, a physical measurement, and a decision — none of which
can be answered from a datasheet, and all three gate fabrication rather than design.

---

## 7. Risks and how each is closed out

### R-0 — No power-electronics expertise in the review loop

**This is the dominant risk and I under-weighted it in the first draft.** It is larger
than any individual circuit risk below, because it is the risk that removes the safety net
under all of them.

**Plain terms:** I can produce a specification that reads correctly, uses the right
formulas, and is still wrong in ways neither of us would spot. Power electronics is
unforgiving — a design that is 95% right does not run 95% as well, it fails. The failures
are concentrated in the things that do not appear on a schematic at all: physical copper
geometry, parasitic inductance in the switching loop, ground return paths, thermal
coupling between parts. Those are learned by building, and 750W of mains-derived power
into $4,200 of computers is an expensive classroom.

**What it costs if unaddressed:** the realistic bad outcome is not "it doesn't work" —
that is recoverable. It is a channel that works on the bench, then fails shorted at 03:00
in month four and puts 48V into a node.

**Decision taken: no external review. Bench testing only.** Recorded as a deliberate
choice, not an oversight. The integrated-FET mitigation also failed on thermals
(§4.3.1.1), so **two of the three planned mitigations for R-0 are unavailable** and the
remaining programme has to carry the full weight. It is set out below and is materially
more demanding than the first draft, because it is now the only thing there is.

**Compensating controls — none require expertise you don't have:**

| # | Control | Cost | What it buys |
|---|---|---|---|
| 1 | **Start from the vendor reference design and log every deviation** | Free | TI publishes a complete LM5116 schematic *and* board layout. Copy the power stage geometry verbatim. Risk concentrates in the deviations, so a written deviation list becomes the review checklist you'd otherwise have paid for |
| 2 | **Buy the LM5116 evaluation board and measure it first** | ~$100 | Gives a *known-good reference*. When your board misbehaves, comparing against a working board separates "my design is wrong" from "my expectations are wrong" — the single hardest thing to judge without experience |
| 3 | **Destructive OVP proof** (§9.1) | ~$5 | Deliberately solder drain-to-source across a high-side FET and confirm the crowbar saves a dummy load. This *is* the failure mode that kills nodes. Do not simulate it — cause it |
| 4 | **Never bench-test into an MS-01** | ~$30 resistive dummy load | Bring-up failures are expected and should be cheap |
| 5 | **72-hour burn-in into dummy loads before any node connects** | Time only | Latent defects — marginal solder, an over-stressed part — surface under sustained heat, not in a 30-minute test |
| 6 | **Re-run fault injection *after* burn-in** | Time only | Confirms protection still works on a thermally-aged board, not just a fresh one |
| 7 | **30-day canary on one worker node** (§9.4) | Time only | **The most valuable control here.** It converts the worst case from "six nodes die" to "one worker dies", and buys a month for latent faults to appear |
| 8 | **Trim the PSU current limit down during bring-up** | Free | RSP-1000-48 output current is trimmable to 40% (§4.5.3). Early faults are gentler |

> **Residual risk is accepted and non-trivial.** Controls 3, 5, 6 and 7 are the ones that
> matter most; 7 in particular is what stops a latent design error from being a
> whole-cluster event. **Stage 4's fault injection and the stage 7 canary are hard gates.**

An offer, not a substitute: I can run a structured design review against TI's published
reference material and a standard power-supply checklist when the schematic exists. That
is weaker than a competent human reviewer and should not be mistaken for one, but it is
better than nothing and it costs only time.

### R-1 — OVP fails and 48V reaches a node · **Critical**

**Plain terms:** the switching transistor that chops 48V down to 19V can fail shorted.
When it does, the full 48V appears at the barrel jack. An MS-01's input stage will not
survive that. The protection has to act in microseconds and has to work when the
regulator, the microcontroller and the firmware have all already failed.

**Cost if it happens:** one MS-01 (~$700). If the cause is common to all channels — a
design error rather than a component failure — up to six (~$4,200).

**How it is closed:**

1. **Crowbar, not just shutdown** (§4.4.2). A shorted transistor cannot be switched off,
   so the protection must short the output instead and blow the fuse. This is already in
   the design and is the correct pattern.
2. **A second, independent clamp.** A TVS diode across each output, sized to conduct hard
   at ~22V, in parallel with the crowbar. Two mechanisms, different failure modes, ~$0.40.
3. **Deliberate fault injection on the bench, into a dummy load, before any node is ever
   connected** (§9.1) — including with the MCU physically removed. Measure what the load
   actually sees. If it exceeds ~22V for any measurable time, the design is not finished.
4. **Proven destructively, not by reasoning.** With no external review (R-0), the
   drain-to-source short test in §9.1 is the *only* real evidence this protection works.
   It is cheap, it is definitive, and it must be performed on a fresh board and again
   after burn-in.
5. **The 30-day canary (§9.4)** bounds the consequence if 1–4 have all missed something.

Residual risk after all five: **moderate, and knowingly accepted.** It would have been low
with an independent review. It never reaches zero on a custom design.

### R-2 — The first high-current board layout is defective · **High**

**Plain terms:** at 250kHz and 48V, whether the circuit works depends on the physical
arrangement of copper as much as on the schematic. Get it wrong and you see overheating,
electrical noise, or instability that no amount of schematic review would have caught.

**Cost:** $30–80 and 2–3 weeks per re-spin. Money and time, not hardware damage.

**How it is closed:** one 2-channel board built and proven before the full set is ordered
(§8, already in the design); vendor reference layout copied verbatim; **budget three board
spins, not one** — a first-time high-current layout that works on the first attempt is
luck, not planning. Plan the schedule and the money around three.

### R-3 — the supply proves marginal · **CLOSED at WP-3**

**Plain terms:** the power supply might run out of headroom under real load.

**This risk existed because the RSP-750-48 was a 753.6W supply carrying a 726W peak —
96% of its rating.** Sourcing found that unit discontinued, and its replacement changed
the arithmetic rather than preserving it:

| | Was (RSP-1000-48) | Now (RSP-1000-48) |
|---|---|---|
| Capacity | 753.6W | 1008W |
| Peak load | **96%** | **72%** |
| Headroom before the question reopens | none | a measurement **38% above** the estimate |

**Closed.** 72% is not a marginal operating point. The chassis was already dimensioned for
this exact unit under M-2, so closing the risk cost nothing but the price difference.

**The measurement is still worth taking**, and it is still the only real evidence behind
§4.2.1 — every figure there is third-party. But it is now **informational rather than a
gate**:

> Buy a plug-in energy meter (~$20). Run all six nodes through a power strip on real
> workloads, then `stress-ng --cpu 0` on all six simultaneously. Record the peak.

An evening's work that replaces five third-party numbers with your own. Do it — just not
before you can order parts.

### R-4 — A firmware fault drops node power · **High if unmitigated**

**Plain terms:** a software bug or a crashed controller kills the cluster.

**How it is closed:** hardware, not software. Outputs are held on by resistors and can
only be turned *off* by the MCU actively pulling a pin down (§4.5.2). An MCU that is
crashed, unprogrammed, unpowered or physically removed leaves every output on. Verified by
pulling the MCU out of its socket and confirming outputs stay up (§9.2).

**One rule that must never be broken:** no firmware feature that turns outputs off on
network loss, watchdog expiry, or any autonomous condition. Outputs turn off only on an
explicit command or a hardware protection event. Residual risk after this: low.

### R-5 — Upstream's BOM defect propagates · **Low**

Identified (§2.4) and the affected circuit is not inherited. No further action.

### R-6 — 226MB of upstream history in the fork · **Low**

Cosmetic. Accepted deliberately in exchange for explicit lineage.

### R-7 — Integrated-FET regulator unavailable · **RESOLVED — and it materialised**

Investigated (§4.3.1.1). The concern was misdirected — output *voltage* was never the
problem, **package dissipation** is. No 60V-class integrated regulator can dissipate the
losses of a 133W channel in its own package. The controller-plus-discrete-FET route is
therefore forced.

**The contingency stated when this risk was written has triggered: the R-0 external review
is now mandatory rather than strongly recommended.** The single mitigation that would have
reduced layout risk for a non-expert builder is not available, so the remaining mitigation
has to carry the full weight.

---

## 8. Build order

Stage-gated. **Do not order the full board set before stage 3 passes.**

| # | Stage | Gate to clear before proceeding |
|---|---|---|
| 0 | **Barrel jack measured with calipers** (OPEN-5). Six-node draw (OPEN-6) is now informational — take it, but it no longer gates | OPEN-5 recorded |
| 1 | **Schematic** — LM5116 channel, protection, control board, backplane | — |
| 2 | **Sourcing** — full BOM, live stock, live pricing | No unsourceable parts |
| 3 | **LM5116 evaluation board** — buy, build, measure (R-0 control 2) | A working reference exists to compare against |
| 4 | **One 2-channel board** — layout → fab → bring-up → fault injection → 72h burn-in → **fault injection again** (§9.1) | 🔴 **Hard gate.** Every fault-injection test passes both before *and* after burn-in, including with the MCU removed and with a FET deliberately shorted |
| 5 | **Control board, display, firmware** against the proven channel board | Fail-ON verified by pulling the MCU; display verified irrelevant to power delivery |
| 6 | **Remaining two boards, chassis, panels**, integration | — |
| 7 | **30-day canary** — one worker node only (§9.4) | 🔴 **Hard gate.** 30 days, no fault, no thermal drift |
| 8 | **Remaining five nodes, six-node soak** | 24h at cluster-typical load |

Stage 0 costs almost nothing and can start today. **Stages 4 and 7 are the gates that now
carry the risk R-0 would otherwise have been reviewed out of.**

---

## 9. Verification

> **A power-supply design cannot be signed off by analysis or simulation. The schematic
> must be reviewed by a competent engineer before money is spent on fabrication, and the
> board must be bench-tested before any MS-01 is connected.** Every figure in §4.3.3 is
> analytical and unverified.

### 9.1 Stage 3 — single board, no MS-01 present

| Check | Requirement | Method |
|---|---|---|
| Regulation | E-1 | 19.0V ±2%, no load → 7A |
| Ripple | E-3 | ≤200 mVpp on a scope at 7A |
| Transient | E-7 | 0→7A load step, recovery within bounds |
| **Switch-node spike** | D-10 | 🔴 **Hard gate.** At 7A, measure the switch node and each FET drain–source on a scope (≥200MHz, short ground spring, not the clip lead). Peak must stay **≤54V (90% of the 60V FET rating)**. Tune the DNP snubber if not; if tuning cannot achieve it, move to 80V FETs |
| Efficiency | E-6 | ≥94% at 7A |
| Thermal | T-2 | 30-min soak at 7A, IR camera on FETs, inductor, sense resistor |
| Telemetry | F-3 | INA226 vs bench meter at 1A / 4A / 7A |

Powered from a **current-limited bench supply**, not the RSP-1000-48, so a fault cannot
deliver 1000W into a mistake.

**Deliberate fault injection — run the full set twice: once on the fresh board, and again
after the 72-hour burn-in.** A protection circuit that works cold and fails on a
thermally-aged board is the exact scenario the canary stage exists to catch, and catching
it here instead is far cheaper.

- Output short → current limit engages, then fuse clears (P-4, P-3)
- Force the OVP reference → crowbar fires, output clamps, input fuse clears (P-1, P-2)
- **Repeat the OVP test with the MCU physically removed** — this is the point of P-1
- **Destructive test — solder a wire drain-to-source across the high-side FET, then power
  up into a dummy load.** Measure what the load actually sees, on a scope, including the
  first few microseconds. This is the failure mode that destroys nodes; it is the one test
  that must not be reasoned about instead of performed. Sacrifice the FET. Expected
  result: load never exceeds ~22V, crowbar fires, input fuse clears.
- Inrush into a 2200µF load without fuse operation (P-8)
- Pull the 48V feed mid-operation; confirm no output overshoot on collapse

**72-hour burn-in** at 7A per channel into dummy loads, logging board temperature. Then
repeat everything above.

### 9.2 Stage 4 — control

- `POST /switch/port_1/turn_off` drops the rail to 0V and the bleed discharges it (P-9)
- `curl http://saturn-pdu.local/metrics` returns plausible per-port values (S-3)
- Fan curve ramps against a heated NTC; tach reports a stalled fan (T-4, T-5)
- **Unplug Ethernet → outputs stay up** (S-4)
- **Hold the MCU in reset → outputs stay up** (F-5, S-4)
- Display shows aggregate and per-node watts matching the bench meter (F-8)
- **Unplug the display entirely → all six outputs stay up and remain controllable over the
  network** (F-9)
- **Single tap anywhere on the display cannot de-energise a node**; power-off requires
  select-then-hold-2s and names the node (F-9)

### 9.3 Stages 5–6 — single-node integration

- One MS-01 powered from the **bench supply** through a full boot and a `stress-ng` run,
  before the RSP-1000-48 is ever in the path
- Remote power cycle brings that node back through POST cleanly (F-2)
- Chassis assembled, fans and display in place, 24-hour soak at that node's typical load
  while monitoring T-1 and T-2

### 9.4 Stage 7 — the 30-day canary

**The most important gate in this document, given the decision on R-0.**

Connect **exactly one channel to exactly one MS-01 — a worker node, never a control-plane
node.** The other five nodes stay on their stock bricks for the full 30 days.

Rationale: every test in §9.1–9.3 is a test you thought to run. A latent design error, by
definition, is one nobody thought of. Thirty days of real duty cycle — real thermal
cycling, real load steps, real idle periods — is the only thing that exercises the cases
no test plan contains. If something is going to fail, this is where it should happen, to
one replaceable worker rather than to the cluster.

**Pass criteria, all thirty days:**

- No protection event of any kind
- No drift in output voltage or in the channel's operating temperature between day 1 and
  day 30
- Node uptime equals or betters the stock brick it replaced
- Logged per-channel telemetry shows no anomaly against the other five nodes' known load

**Any protection event, any measurable thermal drift, or any unexplained node reboot
resets the clock to day zero and requires the cause to be found first.** Not "monitored" —
found.

Only on a clean thirty days do the other five nodes move across.

### 9.5 Stage 8 — full cluster

- Remaining five nodes moved across only after a clean canary month
- Six nodes on the RSP-1000-48; log aggregate draw through synchronised `stress-ng` across
  all six — **this is the empirical answer to §4.2.2** and determines whether the
  RSP-1000-48 swap is warranted
- Remote power cycle verified on every node (F-2)
- 24-hour soak at cluster-typical load, monitoring T-1 and T-2
- Move control-plane nodes across **last**

---

## 10. Repository and licensing

Fork `Shrike-Lab/HomeLab-PDU-V1` → `MarkMckessock/saturn-pdu`.

> Accepted trade-off: the fork carries upstream's 226MB of history permanently; deleting
> files from the working tree does not shrink it. Chosen for explicit lineage.

```
saturn-pdu/
├── LICENSE                     CERN-OHL-S v2, verbatim (L-1)
├── NOTICE                      derivation + changelog vs upstream (L-2)
├── README.md                   architecture, build, safety
├── params.yaml                 ⭐ single source of truth; holds both PROVISIONAL values
├── docs/
│   ├── SPECIFICATION.md        this document
│   ├── power-budget.md         load analysis, derating, PSU headroom
│   ├── thermal.md              airflow, dissipation, fan curve
│   ├── protection.md           fusing, OVP, crowbar coordination, FMEA
│   ├── safety.md              mains vs DC hazards, live-plug handling, bench rules
│   ├── upstream-analysis.md    §2, incl. the Q1 BOM defect
│   └── deviations.md           every departure from TI's reference design (R-0 control 1)
├── hardware/kicad/
│   ├── lib/                    project symbols + footprints
│   ├── saturn-pdu-2ch/         ← build and test this FIRST
│   ├── saturn-pdu-ctrl/
│   └── saturn-pdu-bp/
├── cad/                        parametric FreeCAD Python + STEP/STL exports (L-3)
├── firmware/
│   ├── saturn-pdu.yaml         control board
│   ├── saturn-pdu-display.yaml T-Display-S3 Touch
│   └── protocol.md             UART protocol between them
├── fab/                        gerbers, BOM, pick-and-place
└── reference/upstream-19in/    upstream 19in .stp, dimensional reference
```

Delete from the fork: all 10in variants, all USB-C PD assets, ShrikeLab branding (L-4),
`.github/FUNDING.yml`.

---

## 11. Implementation plan

### 11.0 Toolchain — verified present

| Tool | Status | Note |
|---|---|---|
| **KiCad 10.0.0** | ✅ Installed | `kicad-cli` at `/Applications/KiCad/KiCad.app/Contents/MacOS/kicad-cli`; `pcbnew` Python scripting available via bundled Python 3.9. Opens upstream's 9.0.7 gerbers without issue |
| **gh 2.92.0** | ✅ Authenticated as `MarkMckessock`, SSH | Can fork and push |
| **Python 3.14.4** | ✅ | For BOM tooling and parameter generation |
| **FreeCAD** | ❌ Not installed | `brew install --cask freecad` — needed at WP-6, not before |
| **ESPHome** | ❌ Not installed | `pipx install esphome` — needed at WP-5, not before |
| **poppler** | ❌ Not installed | `brew install poppler` — only to *view* upstream's schematic PDFs. Optional |

### 11.1 Placeholder strategy — how the two skipped measurements are handled

Both deferred measurements become **named parameters with provisional values in a single
file**, `params.yaml` at the repo root. Documentation, firmware and CAD scripts all read
from it. When a real measurement arrives it is changed in exactly one place.

```yaml
# params.yaml — single source of truth. PROVISIONAL values are marked.
output_connector:
  type: barrel_jack
  outer_diameter_mm: 5.5      # PROVISIONAL (OPEN-5) — measure stock MS-01 plug
  inner_diameter_mm: 2.5      # PROVISIONAL (OPEN-5) — 2.1 is the other candidate
  polarity: centre_positive   # PROVISIONAL (OPEN-5)
  panel_thread_mm: 8.0        # NOT provisional — see note below
power_budget:
  per_node_sustained_w: 95    # PROVISIONAL (OPEN-6) — ServeTheHome, not measured
  per_node_turbo_w: 115       # PROVISIONAL (OPEN-6)
  aggregate_design_w: 690     # PROVISIONAL (OPEN-6) — derived
```

**Neither placeholder actually blocks anything, which is why deferring them is safe:**

- **OPEN-5 does not block the chassis.** 5.5×2.5mm and 5.5×2.1mm jacks share the same
  panel-mount thread, so the rear panel cutout is identical either way. Only the *jack part
  number* is provisional, and that is a stage-2 purchasing decision, not a design one.
  Polarity is a wiring decision made at assembly. **Risk if wrong: one wrong $2 part.**
- **OPEN-6 does not block the design.** The architecture already hedges via the
  RSP-1000-48 drop-in (§4.2.3), and the chassis is dimensioned for the larger unit
  regardless. A measurement that comes in higher changes a purchase, not a layout.
  **Risk if wrong: a $165 PSU swap into a chassis already sized for it.**

> Both are carried as **GitHub issues** so they cannot be silently forgotten, and both are
> re-flagged as gates at WP-8 (before ordering) rather than now.

### 11.2 Work packages

Each work package lists its deliverable and who does it. **"Me"** means I can complete it
in-session; **"You"** means it needs hands, a GUI, or money.

#### WP-1 · Repository scaffold — *Me*

1. `gh repo fork Shrike-Lab/HomeLab-PDU-V1 --fork-name saturn-pdu --clone`
2. Branch `main`, no PRs to upstream (this is a divergent derivative, not a contribution)
3. **Remove:** all 10in variants, all USB-C PD assets, ShrikeLab branding and logos (L-4),
   `.github/FUNDING.yml`
4. **Preserve:** upstream 19in `.stp` files → `reference/upstream-19in/` (dimensional
   reference, §4.8)
5. **Add:** `LICENSE` (CERN-OHL-S v2 verbatim, L-1), `NOTICE` (derivation + changelog vs
   upstream, L-2), `README.md`, `params.yaml`, `.gitignore` for KiCad backups/autosaves
6. Directory tree per §10

**Deliverable:** a clean repo that builds nothing yet but is correctly licensed and attributed.

#### WP-2 · Documentation set — *Me*

- `docs/SPECIFICATION.md` — this document
- `docs/power-budget.md` — load analysis, derating, PSU headroom, the 2×450W decision record
- `docs/thermal.md` — dissipation budget, airflow calculation, fan curve
- `docs/protection.md` — fusing, OVP, crowbar coordination, and a written **FMEA** table
- `docs/safety.md` — mains vs DC hazard separation, live barrel-plug handling, bench rules
- `docs/upstream-analysis.md` — §2, including the Q1 BOM defect
- `docs/deviations.md` — **starts empty; every departure from TI's reference design gets a
  row.** This is R-0 control 1 and becomes the review checklist

#### WP-3 · BOM and sourcing — *Me, then You to order*

- `fab/bom.csv` — every part, with manufacturer PN, LCSC/DigiKey/Mouser PNs, live stock
  and qty-10 pricing, checked at time of writing
- Second-source column for every part on the critical path
- Flag anything with <1000 units stock or >8 week lead
- **Refresh §5 cost model against real numbers** rather than estimates

**You:** order the **LM5116 evaluation board** (~$100, R-0 control 2). Long lead — order at
WP-3, it is not needed until WP-8.

#### WP-4 · KiCad — 2-channel power board — *Me for schematic, You for layout*

This is the highest-risk artifact and the plan reflects that.

**4a. Libraries — Me.** Symbols and footprints for LM5116, INA226, XAL1510-223, the chosen
MOSFETs, the OVP comparator and SCR, fuses, TVS, barrel jack. Verified against datasheet
drawings, committed to `hardware/kicad/lib/`.

**4b. Schematic — Me.** Full net-by-net design: power stage, compensation network, current
sense, OVP comparator + crowbar, INA226 telemetry, per-channel fusing and TVS, backplane
connector. Driven to **ERC-clean** via `kicad-cli sch erc`.

> Honest caveat: I author `.kicad_sch` as text. The result will be electrically correct and
> ERC-clean, but the *drawing* will look machine-placed. Expect to spend an hour in the
> Schematic Editor tidying it into something readable — which is also the best way for you
> to actually understand what it does before you build it.

**4c. Board setup — Me.** Board outline, 4-layer stackup (2oz/1oz, §4.6), design rules for
2oz copper and 48V clearances, netlist import, initial component placement via `pcbnew`
scripting.

**4d. Layout and routing — You, at the GUI.** I am not doing this, and it is not a
limitation I am working around — it is the correct division. Per R-2 and R-0 control 1,
the power-stage geometry must be **copied from TI's published LM5116 reference layout**,
which means having it open on screen beside your board. Every deviation gets a row in
`docs/deviations.md`. Driven to **DRC-clean** via `kicad-cli pcb drc`.

**4e. Fab outputs — Me.** Gerbers, drill, IPC-356 netlist, pick-and-place, assembly
drawings via `kicad-cli`. Published as editable source *and* exports (L-3).

#### WP-5 · KiCad — control board and backplane — *Me for schematic, You for layout*

Same split as WP-4, but **materially lower risk** — these are signal-level boards with no
switching power stage.

- **Control board:** ESP32-S3, W5500 Ethernet, 12V-aux input regulator, 6× open-drain
  enable drivers, I²C to 6× INA226, 3× fan PWM + tach, 3× NTC, button input, LED expander,
  UART to the display, DC-OK input
- **Backplane:** passive. 48V distribution (copper pour or busbar for 15.1A), I²C, enable
  lines, board-to-board connectors, bus fuse and TVS

#### WP-6 · Firmware — *Me*

- `firmware/saturn-pdu.yaml` — ESPHome for the control board. Six `switch` entities, six
  `ina226` sensors, fan curve from NTC, tach monitoring, DC-OK, Prometheus endpoint, OTA.
  **Fail-ON semantics enforced in hardware (§4.5.2); the firmware must contain no
  autonomous power-off path** (S-4) — this gets a comment block explaining why, so nobody
  "helpfully" adds one later
- `firmware/saturn-pdu-display.yaml` — ESPHome + LVGL for the T-Display-S3 Touch. Read-only
  aggregate view, per-node rows, two-step confirm for any power action (F-9)
- `firmware/protocol.md` — the UART protocol between them
- Validated with `esphome config` (syntax and schema) — **not** flashed until WP-8

#### WP-7 · Mechanical CAD — *Me for scripts, You to review in the GUI*

FreeCAD is not installed, but the model is authored as **parametric Python** that reads
`params.yaml`, so it can be written now and run once FreeCAD is installed.

- `cad/chassis.py` — 1U enclosure, dimensioned for the **RSP-1000-48** (M-2)
- `cad/panel_front.py` — display window (60.8 × 25.5mm), button, 6 LEDs
- `cad/panel_rear.py` — 6× barrel jack cutouts, IEC inlet, RJ45
- `cad/trays.py` — PSU mount, 3× board trays on the 4× M3 pattern (4 mm corner inset)
- STEP and STL exports committed alongside the scripts (L-3 satisfied by the scripts, not
  the exports)

#### WP-8 · Build and verification — *You*

Follows §8 stages 3–8 and §9 exactly. **This is where the two placeholders must be
resolved**, because they become purchasing decisions:

- Measure the barrel jack → update `params.yaml` → confirm the ordered part
- Measure six-node draw → update `params.yaml`. **No longer a purchasing gate** (R-3 closed);
  it validates §4.2.1 and informs whether a second unit is ever warranted

### 11.3 Sequencing

```
WP-1 scaffold ──► WP-2 docs ──► WP-3 BOM ──┬──► [order eval board, long lead]
                                            │
                     WP-4 power board  ◄────┤
                     WP-5 ctrl+backplane ◄──┤   (these three run in parallel;
                     WP-6 firmware      ◄───┤    none depends on another)
                     WP-7 CAD          ◄────┘
                                            │
                                            ▼
                                  WP-8 build & verify
                          resolve params.yaml placeholders here
```

WP-4 through WP-7 are independent. **WP-6 firmware and WP-7 CAD carry almost no risk and
produce something visible early** — a good place to start if you want momentum before the
power board consumes the attention it deserves.

### 11.4 What I will not do

Stated plainly so there is no ambiguity later:

- **PCB routing of the power stage.** Per R-2 and R-0, it must copy TI's reference
  geometry with a human comparing the two. I can place components and set rules; the
  routing decisions are yours.
- **Flash firmware or run anything on hardware.**
- **Order parts or spend money.**
- **Sign off the design as safe.** The spec's §9 preamble stands: with no external review,
  the bench programme in §9.1 and the canary in §9.4 are what stands between a design
  error and your nodes.

### Follow-ons (out of scope)

- Scrape `/metrics` into Saturn's Prometheus; Gatus check for PDU reachability
- Per-node power panel in Grafana
- LAN-only by design; if the UI is ever exposed externally it requires a Zero Trust entry
  per `CLAUDE.md`

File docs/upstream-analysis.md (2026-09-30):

# Upstream analysis

What was extracted from [Shrike-Lab/HomeLab-PDU-V1](https://github.com/Shrike-Lab/HomeLab-PDU-V1),
how, and what could not be.

This exists to satisfy CERN-OHL-S v2 §3.3 and to make the inheritance decisions
in `NOTICE` auditable rather than asserted.

> The upstream fabrication files are no longer in this repository's working tree
> — they describe a board this project discards. They remain available upstream
> and in this repository's git history (commit `c22372e` and earlier).

---

## 1. Why so little was inherited

Two facts, established before any design work:

**1. The load is incompatible.** The MS-01 takes 19V through a barrel jack and
[cannot be powered over USB-C](https://www.galaxus.at/en/s1/questionandanswer/hello-can-the-mini-pc-also-be-supplied-with-power-via-usb-c-or-is-it-only-possible-with-the-mains-ad-782803);
Minisforum support confirms the barrel jack is required. Every USB-C PD module,
the PD-specific board and the 24V rail are therefore useless here.

**2. Upstream's editable source is in its git history, not its current tree.**
_Corrected at WP-4c (2026-09-30)._ The original census looked only at the 149
files in the current tree, found no `.kicad_*` or `.SLDPRT` files, and concluded
the originals were withheld. **That was wrong.** Upstream committed its KiCad
project (`1U Minilab PSU V2.kicad_sch` / `.kicad_pcb`, commit `8633736`,
2025-12-24) and SolidWorks parts (`CAD/*.SLDPRT`), then removed them from the
tree in `724920b` (2026-02-23). They remain in the history this fork carries,
under CERN-OHL-S v2. Upstream therefore did publish Source.

The reverse-engineering below was done from fabrication outputs before this was
found. Where the KiCad source has since been checked, it agrees (Q1 in §5 is
`IRF9540NPBF`, P-channel, in upstream's own schematic) — with one exception, the
mounting holes, corrected in the table below.

## 2. What was extracted, and from where

| Property | Value | Source file | Method |
|---|---|---|---|
| Board outline | **90 × 130 mm** (X 51.8→141.8, Y −38.3→−168.3) | `Edge_Cuts.gm1` | Coordinate extents |
| Stackup | 2-layer, 1.6mm, 2oz | README, confirmed by pour-heavy layout | Stated + inferred |
| Trace apertures | 0.8 / 1.0 / **2.0 mm max** | `F_Cu.gtl` | Aperture definition list |
| Copper pours | 17 regions top, 1 bottom (GND plane) | `F_Cu.gtl`, `B_Cu.gbl` | `G36` region count |
| Drill sizes | 0.6 / 0.75 / 1.0 / 1.8 / 3.2 mm PTH | `.drl` | Tool tables |
| Mounting holes | ~~3.0 mm NPTH × 4~~ **None.** The four 3.0 mm NPTH are the locating-peg holes of the two Mini-Fit Jr connectors J1/J2 (two each), confirmed in upstream's `.kicad_pcb` | `.drl` | Tool tables — misread; corrected at WP-4c |
| Through-hole netlist | Complete | `HomeLab-PSU-V1_netlist.ipc` | IPC-D-356 parse |
| Part values | Complete | `bom.csv`, `README.md` | Direct |

## 3. Reconstructed topology

```
J1 (Molex Mini-Fit Jr) +24V ─► F1 15A ─► Q1 high-side P-FET ─► +24V_SWITCHED
                                          ▲ gate: R4 100k, D7 12V zener,
                                            R2 47k, R3 100R, latched from J2 button
        D6 SMCJ26A bulk TVS, C1/C2 470µF
                                             │
        ┌────────────┬────────────┬──────────┴─┬────────────┐
     F2 3A        F3 3A        F4 3A        F5 3A        F6 3A
        │            │            │            │            │
     J3/J8       J4/J9      J5/J10      J6/J11      J7/J12    ◄── XPM52C PD modules
     + D1–D5 SMBJ26A TVS, C5–C9 470µF, C10–C14 1µF, C15–C19 100nF
                                             │
                              J13 ─► buck module ─► J15/J16 ─► J17/J18 fan headers
```

**Upstream's board performs no power conversion.** It is a passive fan-out: one
master switch, fusing, TVS clamping, bulk capacitance, and headers for five
purchased PD modules and one purchased buck module.

**This design inverts that — conversion *is* the board.** That single difference
is why the schematic could not be inherited even in outline.

## 4. Inheritance decisions

| Element | Decision | Justification |
|---|---|---|
| Fuse + TVS + bulk cap per channel | **Inherit**, rescaled | Sound pattern. 3A → 5A input fuse; TVS standoff 26V → 58V (bus) / 24V (output) |
| Master switch via latching button | **Inherit the concept, change the implementation** | Drive the PSU's remote ON/OFF rather than commutating 15A of 48V through a FET — an option upstream did not have with the HRP-300 |
| Fan rail from the switched main rail | **Inherit**, add MCU PWM | Upstream tunes RPM by trimming a buck module's output voltage: open-loop and crude |
| ~~4 × 3.0mm NPTH mounting pattern~~ | **Nothing to inherit** — see the correction in §2. saturn-pdu-2ch uses 4 × M3 holes 4 mm in from each corner | — |
| 90 × 130mm board footprint | **Reference only** | A useful sanity check that a 2-channel board fits the tray |
| 19" chassis geometry (`.stp`) | **Inherit as dimensional reference** | True B-rep solids, dimensionally trustworthy — unlike the mesh-only printed parts |
| Power path, PD modules, 24V rail | **Discard** | Incompatible with the load |
| 2-layer / 2oz / 15A stackup | **Discard** | Under-specified for an 800W-class board with switching nodes |

## 5. Defect found in upstream

**`Q1` is specified inconsistently.**

| Source | Part | Type |
|---|---|---|
| `README.md` BOM | `NCEP40PT15D` | **N-channel**, 40V |
| JLCPCB `bom.csv` (LCSC field) | `IRF9540NPBF` | **P-channel**, 100V |

These are opposite polarity and not interchangeable.

**The CSV is correct.** The surrounding gate network settles it: a 100k pull-up
to the source rail, a 12V zener clamping V_gs, and a drive that pulls the gate
*low* to turn the device on. That is unambiguously a **P-channel high-side
switch**. An N-channel device in that circuit would be off when commanded on, and
would need a charge pump or bootstrap that is not present.

**Building from the README alone yields a non-functioning board.** Recorded here
for the benefit of anyone else working from that repository. The affected circuit
is not inherited by this project, so no further action is taken.

## 6. What could not be extracted

**The schematic PDFs contain no machine-readable text.** Both are ~34KB with no
embedded fonts and no `Tj`/`TJ` text-showing operators — KiCad plotted every
label as vector strokes. No net names, designators or values are programmatically
recoverable. Rendering them for human review requires `brew install poppler`.

**The IPC-356 netlist covers through-hole pads only.** SMD connectivity is absent.
The exact wiring of the Q1 gate network in §3 is therefore **inferred from part
values and standard practice, not extracted**. It is almost certainly the textbook
arrangement — and §5's conclusion does not depend on the fine detail, only on the
pull-up-and-pull-low topology, which the part values establish on their own. But
it is an inference and it is labelled as one.

Neither gap is material, because the power path is not being copied.

> **Both gaps are closable** now that upstream's KiCad schematic has been found
> in its git history (§1): `git show 724920b^:"PCB/1U Minilab PSU V2/1U Minilab PSU V2.kicad_sch"`.
> They have not been re-worked, because nothing in this design depends on them.

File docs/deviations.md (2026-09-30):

# Deviations from the reference design

**This file is R-0 control 1.** It is the single most important document in the
repository, and right now it is empty.

---

## Why this exists

There is **no independent review of this design** — a deliberate decision,
recorded as risk R-0 in `SPECIFICATION.md` §7. The compensating strategy is:

1. Start from **TI's published LM5116 reference schematic and board layout**.
2. Copy the power-stage geometry verbatim.
3. **Log every single departure from it here, with the reason.**

Risk concentrates in the deviations. A design that is 95% a proven reference
design plus a written list of the 5% that is not, is a design that can be
reviewed — by you, by a stranger on a forum, by anyone you eventually ask. A
design with no such list can only be reviewed by reading all of it.

**This list is the review checklist you would otherwise have paid for.**

## Rules

- **Every deviation gets a row.** Including ones that seem obviously fine. The
  ones that seem obviously fine are the ones that are not.
- **Write the row when you make the change**, not at the end. You will not
  remember why.
- "Because the reference part was out of stock" is a perfectly good reason.
  Write it down anyway.
- A deviation with an empty **Why** column is a deviation nobody has justified.
  Treat an empty Why as a defect.
- **Layout deviations matter more than schematic deviations.** At 250kHz and 48V,
  physical copper geometry determines whether the circuit works. That is the part
  a schematic review cannot catch and the part this log exists to expose.

## Reference material

| Document | What it is | Status |
|---|---|---|
| TI LM5116 datasheet (SNVS566) | Controller, design equations | To be filed in `reference/` |
| TI LM5116 EVM user guide | **Reference schematic and board layout** | To be filed in `reference/` |
| Coilcraft XAL1510 datasheet | Inductor | To be filed |
| TI INA226 datasheet | Telemetry | To be filed |

**Have the EVM layout open on screen beside the board while routing.** Not from
memory, not from a screenshot in a forum post. Open, side by side.

---

## Schematic deviations

| # | Reference does | This design does | Why | Risk | Checked at |
|---|---|---|---|---|---|
| _(none yet — WP-4b)_ | | | | | |

## Layout deviations

| # | Reference does | This design does | Why | Risk | Checked at |
|---|---|---|---|---|---|
| _(none yet — WP-4d)_ | | | | | |

## Component substitutions

| # | Reference part | Substituted | Why | Datasheet compared? | Risk |
|---|---|---|---|---|---|
| _(none yet — WP-3)_ | | | | | |

---

## Known deviations already committed by the specification

These are decided and are recorded now so the list starts honest rather than
starting empty-and-wrong.

| # | Reference/typical | This design | Why | Risk |
|---|---|---|---|---|
| D-1 | LM5116 EVM runs a lower V_in | **48V input** | The bus voltage, set by the PSU choice | Switching loss scales with V_in — the dominant loss (§thermal.md §3). Drives the 250kHz choice |
| D-2 | Typical EVM output is a low voltage at high current | **19V at 7A (133W)** | The MS-01's input requirement | Duty cycle 0.396 is unremarkable; the power level is what stresses the thermal design |
| D-3 | EVM has no output OVP crowbar | **SCR crowbar + independent comparator per channel** | P-1/P-2: a shorted high-side FET must not reach the node, and protection must work with the MCU unpowered | **This is an addition, not a substitution — it has no reference design behind it at all.** The highest-risk single item in this project |
| D-4 | EVM has no telemetry | **INA226 on each output** | F-3 | Low. Advisory only; nothing switches on a reading |
| D-5 | EVM is a single channel on its own board | **Two channels per board, three boards** | Panelisation, cheap field swap, contained thermal problems | Shared input node between two channels — check the bus-sag ride-through case (protection.md §2) |
| D-6 | EVM enable is a simple pin | **UVLO divider holds enable ON; MCU pulls down via open-drain** | F-5/S-4: fail-ON is a hard requirement | Low, and it fails in the safe direction |
| D-7 | Housekeeping supply taken from a PSU auxiliary rail | **48V bus → LM5164 → 12V/1A → fans; 12V → 5V/1A → logic** | The RSP-1000-48's aux is 5V/0.5A. At ~2.0W estimated draw that is 80% of it — the derating limit, not a margin — and the fans need 12V regardless | Low. The 48V bus is live whenever the PSU is on, independently of any channel's state, which is the exact property the aux rail was wanted for |
| D-8 | EVM uses the FETs TI characterised it with | ~~**Infineon BSC0702LS, 60V 2.7mΩ logic-level, TDSON-8** | The spec's `PSMN5R2-60YS` does not exist and its real equivalent is out of stock. BSC0702LS is lower R_ds(on), lower Q_g and cheaper — but the deciding factor is that it is characterised at V_gs = 4.5V, so its worst case at the LM5116's 7.4V gate drive is bounded rather than guessed~~ **SUPERSEDED by D-10** — fails the LM5116 start-up gate-charge limit | Low on paper, **but the package differs** (TDSON-8 5×6mm vs the EVM's part). Thermal pad geometry and gate-loop length change with it, and those are exactly the layout-sensitive things R-2 is about. Compare against the EVM at stage 3 |
| D-9 | _(no reference equivalent — this is part of D-3)_ | **TL431B replaces the TLV431A named in the WP-3 BOM** | TLV431's cathode is rated 7V absolute maximum. The OVP reference sits across the channel's own **19V** output, so a TLV431 would run at roughly 3× its absolute maximum, continuously, on all six channels. TL431 is rated 37V | **Caught before fabrication, by reading the datasheet while building the KiCad library.** The failure it avoids is the worst kind: the board would have worked on the bench, then the part protecting against a shorted high-side FET (R-1) would have died silently. Note the pinouts differ between the two families, so this is not a drop-in swap — see `hardware/kicad/lib/README.md` §4 |
| D-10 | EVM uses the FETs TI characterised it with | **TI CSD18563Q5A, 60V 6.8mΩ, low-Q_g, VSONP-8 5×6mm** — replaces D-8's BSC0702LS | The LM5116's internal VCC regulator is only guaranteed to supply **15mA**, and the datasheet requires (Q_g,HS + Q_g,LS) × f_sw to stay under that or start-up is not guaranteed. The BSC0702LS pair needs ~68nC at 7.4V drive → **~17mA at 250kHz: over the limit.** CSD18563Q5A is ≤20nC each even at 10V → ~7.5mA typ, ≤10mA worst case. It is also TI's own sync-FET for this class of converter | R_ds(on) is higher (≤10.8mΩ at 4.5V vs 3.9mΩ) → ~+0.3W conduction per channel, partly offset by a much smaller Q_gd (2.9nC) cutting switching loss, which dominates at 48V. **Found at WP-4b by checking the datasheet start-up rule, not by any tool — ERC/DRC cannot see this.** Package change: KiCad's stock TDSON-8-1 does **not** match TI's land pattern; a renumbered project footprint is used (`hardware/kicad/lib/README.md` §3.2). **60V on a 48V bus is 25% headroom — the usual minimum.** Accepted by the owner on 2026-09-30 over an 80V part, on three conditions: the PSU output is locked at 48V and never trimmed up (`params.yaml`); the LS snubber footprint stays on the board; and a hard bench gate requires switch-node spikes ≤54V (SPECIFICATION §9.1) |
| D-11 | EVM is a standalone board | **Board-to-board 2×10 header replaced by three cabled connectors:** Mini-Fit Jr 2×2 (48V in), Mini-Fit Jr 2×4 (two 19V outputs, 2 pins each), 2×6 shrouded 2.54mm header (3.3V, I²C, two OFF lines, NTC, BOARD_ID — every signal beside a ground). The backplane becomes a cable harness | A 2.54mm header pin carries ~3A; one board draws up to 7.3A at 48V and delivers 14A at 19V. Power on a signal header was never viable | Low. Mini-Fit Jr is 9A/pin. **Molex MPNs not yet verified against the footprint** — check before ordering |
| D-12 | _(part of D-3)_ | **OVP drive: TL431 → PNP (MMBTA56) → SCR gate**, instead of feeding the SCR gate from the TL431 anode | Driving the gate from the anode lifts the anode off ground by the gate voltage (~0.6–1V), which moves the TL431's reference point and shifts the trip voltage by the same amount. With the PNP, the TL431 anode stays at ground, so the trip is exactly 2.495 × (1 + 76.8k/10k) = **21.66V** and the PNP sources the gate current from the output itself | Low. One extra SOT-23 part. Still has no reference layout — covered by the D-3 destructive test |
| D-13 | _(no reference equivalent)_ | **INA226 addresses: A1 = BOARD_ID pin (strapped per slot on the harness to GND / 3V3 / SDA), A0 = GND on CH1, 3V3 on CH2** → 0x40/41, 0x44/45, 0x48/49 | Lets three identical boards share one I²C bus with no per-board part changes | Low. A mis-strapped harness produces an address clash, visible immediately at bring-up as a missing or duplicated sensor |
| D-14 | EVM has no thermal sensing | **NTC to GND on each board; pull-up on the control board. Fail-hot is enforced in firmware**, not in hardware | An open NTC reads as *very cold* whichever way the divider is arranged, so no wiring choice makes a broken sensor fail hot on its own. Firmware must treat any out-of-range reading (open or short) as a fault: fans to 100% and an alert. This closes protection.md FMEA row 9 | Medium until WP-6 implements and tests it. **Bench test: unplug the NTC harness and confirm fans go to full** |

**D-3 deserves emphasis.** It is not a deviation from the reference — it is
circuitry the reference does not contain in any form. There is no published
layout to copy for it, and it is the exact circuit that stands between a failed
FET and a destroyed node. It is why the destructive bench test in
`protection.md` §5 item 4 is mandatory and must not be reasoned about instead of
performed.

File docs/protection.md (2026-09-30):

# Protection design and FMEA

**The governing question for this entire document is one failure:** a high-side
MOSFET fails shorted drain-to-source, and 48V appears at a node's 19V input.

Everything else is ordinary engineering. That one case is what destroys hardware,
and it is the case that ordinary protection does not cover.

---

## 1. Why disabling a channel is not protection

Per-channel switching works by pulling the LM5116's UVLO pin low (§4.5.2 of the
specification). This is correct and sufficient for two things:

- commanded on/off switching
- faults the controller itself detects (overcurrent, undervoltage, thermal)

**It is useless against a shorted pass device.** When the high-side FET is a lump
of shorted silicon, turning off the thing that drives its gate changes nothing —
the short does not care whether it is being told to conduct. The output stays
connected to 48V.

This is why requirement **P-2** exists as a separate line from P-1, and it is why
every channel carries a crowbar.

## 2. Overvoltage protection — the crowbar

Each channel has an **OVP comparator with its own voltage reference, powered from
that channel's own output**, independent of the MCU, the firmware and the
regulation loop (P-1).

| Parameter | Value | Why |
|---|---|---|
| Trip point | **21.66V** (2.495V × (1 + 76.8k/10k), 0.1% divider, 1nF filter) | Above 19V + 10% so load-step overshoot does not nuisance-trip; well below the ~25V typical rating of a laptop-style DC input stage |
| Action | Fires an **SCR across the 19V output** | A crowbar shorts the output. It does not try to open a switch, because the switch is what failed |
| Circuit | TL431B → MMBTA56 PNP → BT151 gate (deviations.md D-12) | The PNP keeps the TL431 anode at ground, so the trip point is exact |
| Node sees | ~1.5V (SCR forward drop) | Regardless of what the buck stage is doing |
| Isolation | Fault current flows through the channel's **5A fast-blow 48V input fuse** until it clears | The crowbar protects; the fuse isolates |

**Division of labour, stated explicitly because it is the part people get wrong:**
the crowbar does not clear the fault, and the fuse does not act fast enough to
protect the node. The crowbar clamps in microseconds and holds; the fuse opens in
milliseconds and makes it permanent. Neither works alone.
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

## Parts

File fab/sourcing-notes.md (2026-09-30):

# Sourcing notes — WP-3

**Checked 2026-09-30.** Prices and stock move. Everything here must be re-checked at the
moment you actually order, and the `verified` column in `bom.csv` says which lines were
looked up live and which are catalogue estimates.

| `verified` | Meaning |
|---|---|
| `LIVE` | Distributor page or listing read on 2026-09-30. Stock and price are real numbers from that day |
| `EST` | Catalogue-typical part and price. Not looked up. Commodity items — resistors, ceramics, TVS, fuses — where the risk is a few cents, not availability |
| `OPEN` | No part selected. A decision is required — **none remain** |

Thirteen lines were verified live: everything on the critical path, everything expensive,
and everything that turned out to be wrong.

---

## 1. Three things the spec got wrong

### 1.1 The specified MOSFET does not exist

`SPECIFICATION.md` §4.3.3 names **PSMN5R2-60YS**. There is no such Nexperia part. The real
one is **PSMN5R5-60YS** — same 5.2mΩ, same 60V, same LFPAK56 — and it is **out of stock at
LCSC** ($2.16, zero units).

**Substituted: Infineon BSC0702LS.** It is better on every axis that matters, and it is the
cheapest of the three:

| | PSMN5R5-60YS (spec'd) | **BSC0702LS (fitted)** |
|---|---|---|
| V_ds | 60V | 60V |
| R_ds(on) @ V_gs = 10V | 5.2mΩ max | **2.7mΩ max** |
| R_ds(on) @ V_gs = 4.5V | not characterised | **3.9mΩ max** |
| Q_g @ 10V | 56nC | **43nC** |
| Package | LFPAK56 | TDSON-8 (SuperSO8, 5×6mm) |
| LCSC stock | **0** | **8,427** |
| Price @ 10 | $2.16 | **$1.38** |

**The logic-level rating is the part that matters.** The LM5116 drives its gates from an
internal 7.4V rail, not 10V. A standard-level FET characterised only at 10V is being run
below its spec point, and you are guessing at the real R_ds(on). The BSC0702LS is
characterised at 4.5V as well, so 7.4V sits comfortably between two specified points and
the worst case is bounded by the 3.9mΩ figure rather than estimated.

**Effect on the loss budget** (§4.3.3, per channel at 7A, R_ds(on) hot = 1.5× the 4.5V max
figure = 5.85mΩ — deliberately the pessimistic end):

| | Spec'd | Fitted |
|---|---|---|
| HS conduction | 0.16W | 0.12W |
| LS conduction | 0.23W | 0.17W |
| Gate drive | 0.11W | 0.08W |

Roughly 0.13W per channel, 0.8W across six. Not significant — **switching loss still
dominates at 1.68W** and none of this changes that. The reason to prefer the part is
availability and a bounded worst case, not the 0.8W.

Recorded as **D-8** in `deviations.md`.

> **Superseded at WP-4b — see D-10.** The table above compares R_ds(on) and never checked
> the LM5116's start-up rule: the controller's VCC regulator is only guaranteed to 15mA and
> must supply (Q_g,HS + Q_g,LS) × f_sw. The BSC0702LS pair at 7.4V is ~68nC → ~17mA at
> 250kHz, which fails. **Fitted instead: TI CSD18563Q5A** — Q_g 15nC typ / 20nC max at 10V,
> so ~7.5mA per pair; R_ds(on) 6.8mΩ max at 10V, 10.8mΩ at 4.5V. LCSC (C77239) is out of
> stock; Mouser listed 7,364 at $1.23 @ 10 and DigiKey 236 on 2026-09-30. Second source:
> Infineon BSC094N06LS5 (TDSON-8, would need the stock `TDSON-8-1` footprint instead).

### 1.2 The inductor's ratings were misread — but the choice holds

`SPECIFICATION.md` §4.3.2.1 records the XAL1510-223 as "I_sat 18.7A, DCR 14.5mΩ".
Distributor listings say "14A, 0.016 Ω". Both are correct; they are **different
parameters**, and the spec quoted one of each:

| Parameter | Value | What it means |
|---|---|---|
| **I_sat** | **18.7A** | Current at which inductance drops 30%. The saturation limit |
| **I_rms** | **14A** | Current for a 40°C temperature rise. The thermal limit |
| DCR typ | 14.5mΩ | Typical |
| DCR max | **16mΩ** | Worst case — the number to design to |

**The 2.3× saturation margin claimed in §4.3.2.1 is real** (18.7A against an 8.04A peak),
and I_rms 14A against 7A RMS is a further 2× on the thermal limit. The part is correctly
chosen. The only correction is that the loss calculation should use the **16mΩ maximum**,
not the 14.5mΩ typical: conduction loss is **0.78W**, not 0.71W. Add 0.4W across six
channels to the chassis thermal budget. Still inside the 38W in `thermal.md`.

### 1.3 The cost model was wrong in both directions

| Line | Spec estimate | Actual | Delta |
|---|---|---|---|
| LM5116 | $5.13 | **$1.88** | −$3.25 |
| INA226 | $2.50 | **$0.63** | −$1.87 |
| MOSFETs ×2 | $1.80 | **$2.76** | +$0.96 |
| Inductor | $3.50 | **$7.55** | **+$4.05** |
| **Per channel** | **~$25** | **~$21.30** | **−$3.70** |

The inductor is now the most expensive part in the channel — more than the controller and
both FETs combined. That is the price of the 2.3× saturation margin, and it is still the
right trade, but it is worth knowing where the money goes.

---

## 2. Long lead and low stock — order these first

| Part | Situation | What to do |
|---|---|---|
| **LM5116-12EVAL/NOPB** — $136.12 | **3–5 units in stock across all distributors. 12-week factory lead** | **Order at WP-3, today.** It is not needed until build stage 3, but there will not be one in 12 weeks if you wait. This is R-0 control 2 and it is the only known-good reference you will have |
| **Mean Well RSP-1000-48** — $267.90 | 211 at DigiKey, 331 at Mouser, **but a 17–19 week factory lead**. Mouser shows 390 more arriving 2026-11-02 | Buy it when you commit to the build, not after. The RSP-750-48 went end-of-life while this document was being written; do not assume stock persists |
| **LILYGO T-Display-S3 Touch** — $25 | **Single source.** Not stocked by DigiKey or Mouser. No distributor part fits 1U | **Buy two.** If LILYGO discontinues it there is no drop-in, and F-8 becomes a redesign |
| Nexperia PSMN5R5-60YS | Out of stock at LCSC | Not used. Kept as the second source, from DigiKey/Mouser |

Everything else on the critical path has four-figure stock: LM5116 19,990 · INA226 43,755 ·
BSC0702LS 8,427 · LM5164 13,462.

---

## 3. OPEN-8 — RESOLVED

**Locking was dropped** (user decision, 2026-09-30). That reduced the requirement from
"panel-mount, locking, 5.5 × 2.5mm, ≥7A" — which does not exist — to "5.5 × 2.5mm, ≥7A",
which does.

**Fitted: Kycon KLDHCX-8-0202-B.** 8A, 24VDC, 5.5mm OD / 2.5mm ID, right-angle through
hole, $1.81 at qty 10, **5,196 in stock at Mouser** and 104 at DigiKey.

### Why this was hard to find

| Manufacturer | Panel-mount 5.5 × 2.5mm ceiling |
|---|---|
| Same Sky (ex-CUI) | **5.0A** across their entire panel-mount line (PJ-005B, PJ-064B, PJ-065B, PJ-066B, PJ-067B, PJ-090BH) |
| Switchcraft | 5A |
| Kycon, panel-mount | 5A |
| **Kycon, PCB right-angle** | **8A — KLDHCX-8 series** |

The 5.5 × 2.5mm barrel is a consumer-laptop connector and the whole industry treats 5A as
its ceiling **when it is panel-mounted**. The higher-rated parts exist only as board-mount,
because the current rating depends on the termination and a soldered PCB joint carries more
than a panel jack's solder tags.

### The consequence: a new small board

KLDHCX-8-0202-B is right-angle through-hole, so **it cannot bolt to the rear panel.** It
goes on a small 2-layer **output board** behind the panel carrying all six jacks, with the
barrels protruding through six clearance holes. Added to `bom.csv` as assembly `OUT`
(~$20 including the board).

That board is also the natural home for the six output TVS diodes, which moved there from
the 2-channel boards — a clamp belongs next to the connector it protects, not 150mm of wire
away.

### Margin

| | Current | vs 8A rating |
|---|---|---|
| Sustained (measured, six nodes) | ~5.0A | 63% |
| Turbo, ~45s | ~6.05A | 76% |
| Channel design capability (E-2) | 7A | 88% |
| Channel current limit (P-4) | ~10.5A | **131% — fault only** |

Comfortable on every real operating point. The 7A in E-2 is what the *channel* can deliver,
not what the *load* draws. Above the current limit the jack is over its rating, but that is
a fault condition the crowbar and fuse exist to end in milliseconds.

### What dropping the locking requirement costs

Recorded honestly in `docs/safety.md` §2: the locking collar was one of four controls
against a dangling live plug, and **the P-12 unconnected-output alert and the operating
procedure are now the whole response.** That is a thinner set than the earlier draft
claimed. It is judged acceptable because the hazard is ES1 to a person, is inherited from
the six existing bricks rather than introduced by this design, and — unlike a brick — can
be de-energised from anywhere.

---

## 4. Refreshed cost model

Replaces `SPECIFICATION.md` §5.

| | Cost |
|---|---|
| 6 buck channels (silicon, magnetics, protection, passives) | $126 |
| 3× 2-channel PCBs, 4-layer | $20 |
| Control board | $31 |
| T-Display-S3 Touch | $25 |
| Backplane + bus fuse | $28 |
| PCBA setup and assembly | $120 |
| **Electronics** | **$370** |
| Mean Well RSP-1000-48 | $268 |
| 3× Noctua NF-A4x20 PWM | $45 |
| IEC inlet, latching button, PSU mating connector | $18 |
| 6× 18AWG interconnect cables | $30 |
| Sheet metal, printed panels, fasteners, bus wiring | $135 |
| **Chassis and power** | **$496** |
| Output board (6× jacks + TVS + PCB) | $20 |
| **Build cost, one unit** | **$937** |
| LM5116 evaluation board (one-off, R-0 control 2) | $136 |
| **First unit, all in** | **$1,074** |

**Plus board re-spins.** R-2 says budget three, at $30–80 and 2–3 weeks each: **add
$150–250.** A realistic first-unit figure is **$1,200–1,330.**

Against the spec's $780–860 estimate this is up about $150, almost entirely the PSU
($268 rather than $165 — the RSP-750-48 was cheaper before it was discontinued) and the
inductor. The silicon came in under estimate.

**The honest comparison in §5 of the specification still stands, and is now slightly worse
for this project:** six stock Minisforum bricks are $240–360, and a used switched-and-
metered rack PDU driving those bricks gets you remote switching and per-outlet metering for
$150–300 in an afternoon. What $1,200 buys over that is the 1U consolidation and the
elimination of six bricks. That was always the actual reason, and it is a fine one.

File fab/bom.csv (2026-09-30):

assembly | ref | qty_per_asm | asm_count | qty_total | description | value | package | manufacturer | mfr_pn | distributor | dist_pn | stock | unit_price_qty10 | ext_price | second_source | verified | flags | notes
2CH | U101 U201 | 2 | 3 | 6 | Synchronous buck controller 6-100V current-mode | LM5116 | HTSSOP-20-EP | Texas Instruments | LM5116MHX/NOPB | LCSC | C13755 | 19990 | 1.88 | 11.28 | DigiKey 296-23623-1-ND | LIVE |  | Qty-100 drops to $1.42. Spec estimated $5.13 - came in far under
2CH | Q101 Q102 Q201 Q202 | 4 | 3 | 12 | N-ch MOSFET 60V 6.8mR logic-level low-Qg | CSD18563Q5A | VSONP-8 (SON 5x6) | Texas Instruments | CSD18563Q5A | Mouser | CSD18563Q5A | 7364 | 1.23 | 14.76 | DigiKey (236 stock) / Infineon BSC094N06LS5 | LIVE | SUBSTITUTION | Replaces the WP-3 BSC0702LS (D-8, superseded by D-10). The LM5116 VCC regulator is only guaranteed to 15mA and TI requires (Qg_HS + Qg_LS) x fsw < 15mA for startup. BSC0702LS at 7.4V drive is ~68nC per pair = ~17mA at 250kHz: FAILS. CSD18563Q5A Qg is 15nC typ / 20nC max at 10V, so the pair at 7.4V is ~7.5mA typ and <=10mA worst case. Rds(on) max 6.8mR at 10V, 10.8mR at 4.5V. LCSC C77239 OUT OF STOCK; Mouser/DigiKey stock taken from search results 2026-09-30, reverify before ordering. Footprint saturn-pdu:TI_VSONP-8_5x6mm_P1.27mm.
2CH | L101 L201 | 2 | 3 | 6 | Power inductor shielded | 22uH | XAL1510 15.5x16.5x10mm | Coilcraft | XAL1510-223MEB | Mouser | 994-XAL1510-223MEB | stocked | 7.55 | 45.30 | Wurth 74439370220 | LIVE | COST_OVERRUN | Spec estimated $3.50; actual ~$7.55. Single largest per-channel overrun. See sourcing-notes.md for the Isat/Irms reconciliation.
2CH | U102 U202 | 2 | 3 | 6 | Bidirectional current/power monitor I2C | INA226 | VSSOP-10 | Texas Instruments | INA226AIDGSR | LCSC | C49851 | 43755 | 0.63 | 3.78 | DigiKey 296-35892-1-ND | LIVE |  | Spec estimated $2.50. Qty-100 drops to $0.55
2CH | R103 R203 | 2 | 3 | 6 | Current-sense resistor for LM5116 CS | 7mR 1W 1% | 2512 | Bourns | CRA2512-FZ-R007ELF | LCSC | - | - | 0.45 | 2.70 | Vishay WSL2512R0070FEA | EST |  | Value per SPECIFICATION.md 4.3.3. Confirm against final current-limit calculation at WP-4b
2CH | R118 R218 | 2 | 3 | 6 | Telemetry shunt for INA226 | 2mR 1W 1% 50ppm | 2512 | Vishay | WSL2512R0020FEA | LCSC | - | - | 0.40 | 2.40 | Bourns CRA2512-FZ-R002ELF | EST |  | 14mV at 7A = 17% of INA226 range
2CH | C109-C110 C209-C210 | 12 | 3 | 36 | Output bulk capacitor polymer low-ESR | 220uF 35V | D8 SMD | Panasonic | EEHZA1V221P | LCSC | - | - | 1.20 | 43.20 | Nichicon PCJ1V221MCL1GS | EST |  | 2 per channel
2CH | C111-C114 C211-C214 | 24 | 3 | 72 | Output ceramic | 22uF 50V X7R | 1210 | Murata | GRM32ER71H226KE15L | LCSC | - | - | 0.25 | 18.00 | Samsung CL32B226KAJNNNE | EST |  | 4 per channel
2CH | C101-C102 C201-C202 | 12 | 3 | 36 | Input bulk capacitor | 100uF 63V | D10 SMD | Panasonic | EEEFK1J101P | LCSC | - | - | 0.55 | 19.80 | Nichicon UCD1J101MNL1GS | EST |  | 2 per channel. Sized for ride-through during a crowbar event on a neighbouring channel (protection.md)
2CH | C103-C106 C203-C206 | 24 | 3 | 72 | Input ceramic | 2.2uF 100V X7R | 1210 | Murata | GRM32ER72A225KA35L | LCSC | - | - | 0.30 | 21.60 | TDK C3225X7S2A225K | EST |  | 4 per channel
2CH | U103 U203 | 2 | 3 | 6 | Precision shunt reference for OVP sense | TL431B | SOT-23-3 | Texas Instruments | TL431BIDBZR | LCSC | C41283 | 10980 | 0.05 | 0.30 | Diodes TL431BSA-7 | LIVE | CORRECTION | OVP comparator per P-1. Powered from the channel's own 19V output - independent of the MCU. CORRECTED from TLV431A: TLV431 VKA abs max is 7V and this reference sits across the 19V output - see hardware/kicad/lib/README.md section 4. TL431 VKA abs max 37V. Pinouts differ between the families (TL431 DBZ = 1 K, 2 REF, 3 A) so this is not a drop-in swap. Vref 2.495V, B grade = 0.5 percent.
2CH | Q105 Q205 | 2 | 3 | 6 | Thyristor crowbar 12A 500V | BT151-500R | TO-220AB | WeEn | BT151-500R.127 | LCSC | C9211 | stocked | 0.82 | 4.92 | ON MCR12DCMT4G | LIVE |  | ITSM 120A/10ms = 72 A2s. Fault is 21A for 10-50ms = 22 A2s. 3x margin
2CH | F101 F201 | 2 | 3 | 6 | Fuse fast-blow 5A 125V | 5A F | Nano2 / 2410 SMD | Littelfuse | 0453005.MR | LCSC | - | - | 0.45 | 2.70 | Bel 0685H5000-01 | EST |  | Coordinates with the crowbar per protection.md
2CH | D101 D201 | 2 | 3 | 6 | TVS bus clamp | SMCJ58A | SMC / DO-214AB | Littelfuse | SMCJ58A | LCSC | - | - | 0.18 | 1.08 | Bourns SMCJ58A | EST
2CH | R119 R219 | 2 | 3 | 6 | Output bleed resistor | 4.7k 1W | 2512 | Yageo | RC2512JK-074K7L | LCSC | - | - | 0.06 | 0.36 | - | EST |  | P-9: a commanded power cycle must actually discharge
2CH | RT1 | 1 | 3 | 3 | NTC thermistor board temperature | 10k B3950 | 0603 | Murata | NCP18XH103F03RB | LCSC | - | - | 0.12 | 0.36 | Vishay NTCS0603E3103FMT | EST |  | NTC to GND; pull-up on the control board. An open NTC reads COLD whichever way it is wired, so fail-hot is a FIRMWARE rule (WP-6): any out-of-range reading = fans 100% and alarm. FMEA row 9
2CH | J1 | 1 | 3 | 3 | 48V input connector 2x2 | Mini-Fit Jr 2x2 | THT vertical 4.2mm | Molex | 5566-04A (MPN TBC) | Mouser | - | - | 0.90 | 2.70 | Amphenol Minitek Pwr 4.2 | EST |  | Pins 1-2 +48V, 3-4 GND. 9A/pin against 7.3A/board worst case. Replaces the 2x10 board-to-board header: backplane becomes a cable harness (D-11)
2CH | J2 | 1 | 3 | 3 | 19V output connector 2x4 | Mini-Fit Jr 2x4 | THT vertical 4.2mm | Molex | 5566-08A (MPN TBC) | Mouser | - | - | 1.40 | 4.20 | Amphenol Minitek Pwr 4.2 | EST |  | Pins 1-2 VOUT1, 3-4 GND, 5-6 VOUT2, 7-8 GND. Two pins per rail = 3.5A/pin at 7A
2CH | J3 | 1 | 3 | 3 | Control signal header 2x6 shrouded | IDC 2x6 2.54mm | THT vertical | Amphenol | - (generic box header) | LCSC | - | - | 0.15 | 0.45 | any | EST |  | +3V3 / I2C / CH1_OFF / CH2_OFF / NTC / BOARD_ID, every signal paired with a GND. I2C pull-ups live on the control board
2CH | Q103 Q203 | 2 | 3 | 6 | Remote-disable pulldown on UVLO | 2N7002 | SOT-23 | onsemi | 2N7002 | LCSC | C8545 | stocked | 0.02 | 0.12 | BSS138 | EST |  | MOVED from CTRL. Gate has 100k to GND so an absent/unpowered control board leaves the channel ON (F-5/S-4)
2CH | Q104 Q204 | 2 | 3 | 6 | OVP gate-drive PNP 80V | MMBTA56 | SOT-23 | onsemi | MMBTA56LT1G | LCSC | - | - | 0.03 | 0.18 | Nexperia MMBTA56 | EST |  | New at WP-4b: TL431 sinks base current, PNP sources SCR gate current from VOUT. Keeps the TL431 anode at GND so the 21.66V trip point is exact
2CH | D102 D103 D202 D203 | 4 | 3 | 12 | Small-signal diode 100V (bootstrap + CFT discharge) | BAS316 | SOD-323 | Nexperia | BAS316 | LCSC | - | - | 0.02 | 0.24 | Diodes BAS316-7-F | EST |  | Bootstrap diode VCC->HB (TI EVM uses CMPD2003), and UVLO->VIN_F discharge diode that the LM5116 datasheet requires with CFT
2CH | R106 C108 R206 C208 | 0 | 3 | 0 | LS switch-node snubber (DNP) | 2.2R 1206 + 1nF 100V 0805 | - | various | - | LCSC | - | - | 0.02 | 0.00 | - | EST | DNP | Footprint only. Fit and tune if the D-10 bench gate (switch-node spike <=54V) fails
2CH | passives | ~76 | 3 | 228 | Compensation, feedback, UVLO/OVP dividers, VCC/HB caps, 0R gate/Kelvin links, decoupling | assorted | 0603/0805 | various | - | LCSC | - | - | 0.012 | 2.74 | - | EST |  | Full values in hardware/kicad/saturn-pdu-2ch schematic. RFB 17.8k/1.21k and OVP 76.8k/10k MUST be 0.1%
2CH | PCB | 1 | 3 | 3 | 4-layer 2oz outer / 1oz inner 1.6mm | - | 90x130mm approx | JLCPCB | - | JLCPCB | - | - | 6.67 | 20.00 | PCBWay | EST |  | 5pcs minimum order; price is per used board
CTRL | U10 | 1 | 1 | 1 | Microcontroller module | ESP32-S3-WROOM-1-N16R8 | module | Espressif | ESP32-S3-WROOM-1-N16R8 | LCSC | C2913202 | stocked | 3.50 | 3.50 | ESP32-S3-WROOM-1U | EST
CTRL | U11 | 1 | 1 | 1 | SPI Ethernet controller | W5500 | LQFP-48 | WIZnet | W5500 | LCSC | C32843 | stocked | 3.80 | 3.80 | - | EST |  | S-1: wired Ethernet not WiFi
CTRL | J10 | 1 | 1 | 1 | RJ45 with integrated magnetics | HR911105A | THT | HanRun | HR911105A | LCSC | C86586 | stocked | 1.80 | 1.80 | Pulse J0011D01BNL | EST
CTRL | U12 | 1 | 1 | 1 | Housekeeping buck 100V 1A integrated FET | LM5164 | SO PowerPAD-8 | Texas Instruments | LM5164DDAR | LCSC | C477928 | 13462 | 1.54 | 1.54 | LM5165 (lower current) | LIVE |  | D-7: 48V bus -> 12V/1A. Replaces the PSU aux rail, which is 5V/0.5A on the RSP-1000-48
CTRL | U13 | 1 | 1 | 1 | 12V to 5V step-down 1A | TPS562201 | SOT-23-6 | Texas Instruments | TPS562201DDCR | LCSC | C120167 | stocked | 0.55 | 0.55 | MP2315 | EST |  | Feeds ESP32-S3 / W5500 / display / INA226 bus
CTRL | U14 | 1 | 1 | 1 | I2C I/O expander for status LEDs | PCA9555 | TSSOP-24 | NXP | PCA9555PW | LCSC | C36846 | stocked | 1.10 | 1.10 | TCA9535 | EST |  | F-6. Conserves MCU GPIO
CTRL | - | 0 | 1 | 0 | (was: 6x 2N7002 enable pulldowns) | - | - | - | - | - | - | - | 0 | 0 | - | EST |  | Moved to the 2CH boards (Q103/Q203). Control board drives CHn_OFF high (3.3V push-pull GPIO) to disable
CTRL | misc | 1 | 1 | 1 | Crystal, USB-C programming port, connectors, decoupling, level shifting | assorted | - | various | - | LCSC | - | - | 4.00 | 4.00 | - | EST
CTRL | PCB | 1 | 1 | 1 | 4-layer 1.6mm | - | ~80x100mm | JLCPCB | - | JLCPCB | - | - | 15.00 | 15.00 | PCBWay | EST
DISP | U20 | 1 | 1 | 1 | 1.9in 170x320 IPS + CST816 capacitive touch | T-Display-S3 Touch | module 60.8x25.5mm | LILYGO | T-Display-S3 Touch | LILYGO store | - | stocked | 25.00 | 25.00 | none - see notes | EST | SINGLE_SOURCE | No distributor equivalent fits 1U (SPECIFICATION.md 4.5.6). Not a tier-1 part and not stocked by DigiKey/Mouser. Buy two.
BP | - | 1 | 1 | 1 | Backplane: 48V distribution, I2C, enable lines, 3x board connectors, bus fuse holder, TVS | - | - | various | - | LCSC | - | - | 12.00 | 12.00 | - | EST |  | Passive
BP | F10 | 1 | 1 | 1 | Bus fuse 20A | 20A | ANL / blade + holder | Littelfuse | - | - | - | - | 6.00 | 6.00 | - | EST |  | P-6
BP | PCB | 1 | 1 | 1 | 2-layer 2oz | - | - | JLCPCB | - | JLCPCB | - | - | 10.00 | 10.00 | PCBWay | EST
CHASSIS | PSU1 | 1 | 1 | 1 | AC-DC PSU 48V 21A 1008W active PFC | RSP-1000-48 | 295x127x41mm | Mean Well | RSP-1000-48 | DigiKey | 1866-3225-ND | 211 | 267.90 | 267.90 | Mouser 709-RSP-1000-48 (331 in stock) | LIVE | LONG_LEAD | In stock now, but 17-19 week FACTORY lead. Buy when you buy, do not assume it will be there later. Mouser shows 390 units on order for 2026-11-02
CHASSIS | J50 | 1 | 1 | 1 | PSU CN50 mating connector + crimp contacts | DF11-12DS-2C | - | Hirose | DF11-12DS-2C | DigiKey | H2025-ND | stocked | 2.20 | 4.00 | - | EST |  | Remote ON/OFF (pin 6 to pin 2/-S), DC OK, remote sense. Includes DF11-2428SCF crimps
CHASSIS | FAN1-3 | 3 | 1 | 3 | 40x20mm PWM fan with tach | NF-A4x20 PWM | 40x40x20mm | Noctua | NF-A4x20 PWM | Amazon/DigiKey | - | stocked | 15.00 | 45.00 | Sunon MF40202VX-1000U-A99 | EST |  | T-4/T-5
CHASSIS | J60 | 1 | 1 | 1 | IEC C14 inlet fused with switch | - | panel | Schurter | - | DigiKey | - | stocked | 6.00 | 6.00 | Qualtek | EST |  | P-5/P-11
CHASSIS | SW1 | 1 | 1 | 1 | Latching illuminated pushbutton 16mm | - | panel | - | - | - | - | stocked | 8.00 | 8.00 | - | EST |  | F-4. Drives PSU remote ON/OFF - no 15A commutation anywhere
OUT | J1-J6 | 6 | 1 | 6 | DC power jack high-current 8A | 5.5x2.5mm | THT right-angle | Kycon | KLDHCX-8-0202-B | Mouser | 538-KLDHCX-8-0202-B | 5196 | 1.81 | 10.86 | DigiKey 2092-KLDHCX-8-0202-B-ND (104) | LIVE |  | OPEN-8 RESOLVED. 8A / 24VDC. Right-angle THT so it mounts on the output board, not the panel - barrels protrude through six clearance holes. 8A against a 6.05A turbo peak = 32% margin
OUT | D10-D15 | 6 | 1 | 6 | TVS output clamp (moved from 2CH) | SMCJ22A | SMC / DO-214AB | Littelfuse | SMCJ22A | LCSC | - | - | 0.18 | 1.08 | Bourns SMCJ22A | EST |  | Co-located with the jack it protects
OUT | PCB | 1 | 1 | 1 | 2-layer output board carrying 6x jacks + TVS | - | ~180x25mm | JLCPCB | - | JLCPCB | - | - | 8.00 | 8.00 | PCBWay | EST |  | New assembly - consequence of the jack being right-angle THT rather than panel-mount
CHASSIS | CBL1-6 | 6 | 1 | 6 | Interconnect cable 18AWG 500mm | 5.5x2.5 barrel plug both ends | - | - | - | - | - | - | 5.00 | 30.00 | - | EST |  | Both ends male. Not locking - see docs/safety.md S2 for the operating procedure that replaces it
CHASSIS | - | 1 | 1 | 1 | Sheet metal 1U chassis, 3D-printed panels, fasteners, standoffs | - | - | - | - | - | - | - | 120.00 | 120.00 | - | EST
CHASSIS | - | 1 | 1 | 1 | 48V bus wiring, lugs, heatshrink, ferrules | - | - | - | - | - | - | - | 15.00 | 15.00 | - | EST
SERVICE | - | 1 | 1 | 1 | PCBA setup + assembly (3x 2ch panelised + ctrl + bp) | - | - | JLCPCB | - | JLCPCB | - | - | 120.00 | 120.00 | PCBWay | EST |  | Setup fee dominates - this is why 3 identical boards panelise
TOOLING | - | 1 | 1 | 1 | LM5116 evaluation board (R-0 control 2) | LM5116-12EVAL/NOPB | - | Texas Instruments | LM5116-12EVAL/NOPB | DigiKey | 296-29236-ND | 5 | 136.12 | 136.12 | Arrow (3 units @ $118.81) | LIVE | LONG_LEAD;LOW_STOCK | ORDER FIRST. 3-5 units in stock across all distributors, 12-week factory lead. Not needed until stage 3, but it will not be there in 12 weeks if you wait

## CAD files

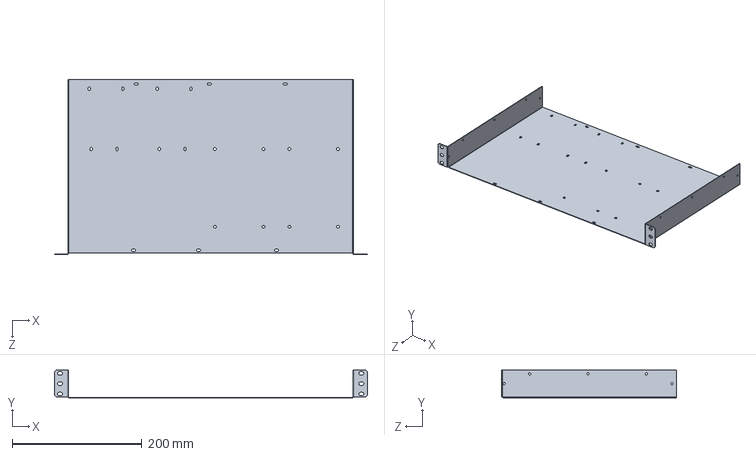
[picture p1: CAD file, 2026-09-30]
reference/upstream-19in/19in_Dual_SBS-Tray.stp
483.2 x 43.0 x 270.0 mm

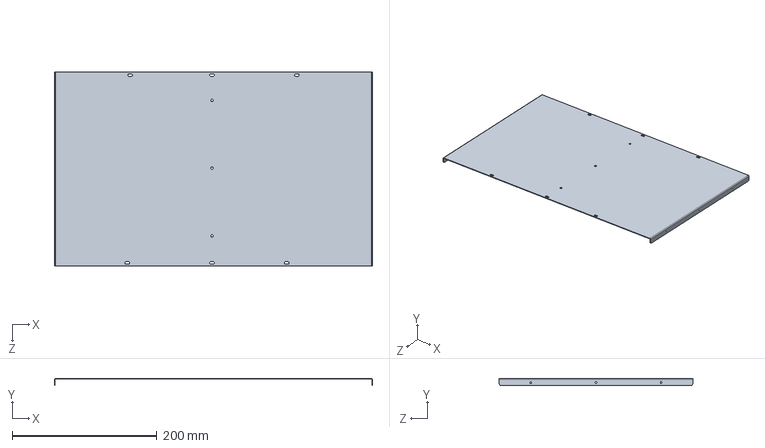
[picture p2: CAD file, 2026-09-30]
reference/upstream-19in/19in_Single-Lid.stp
438.7 x 10.0 x 267.1 mm

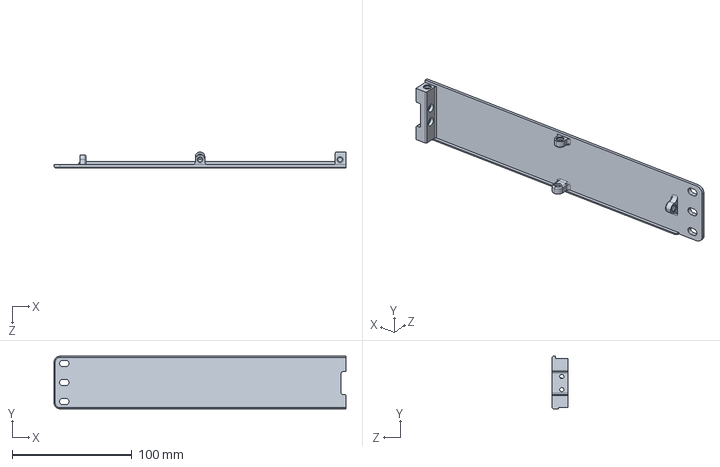
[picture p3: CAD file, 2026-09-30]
reference/upstream-19in/19in_Single-Rear_2-BLANK.STEP
244.1 x 44.0 x 13.4 mm

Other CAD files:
reference/upstream-19in/19in_Single-Tray.stp
reference/upstream-19in/19in_Dual-Lid.stp
reference/upstream-19in/19in_Dual_SBS-Lid.stp
reference/upstream-19in/19in_Dual-Tray.stp

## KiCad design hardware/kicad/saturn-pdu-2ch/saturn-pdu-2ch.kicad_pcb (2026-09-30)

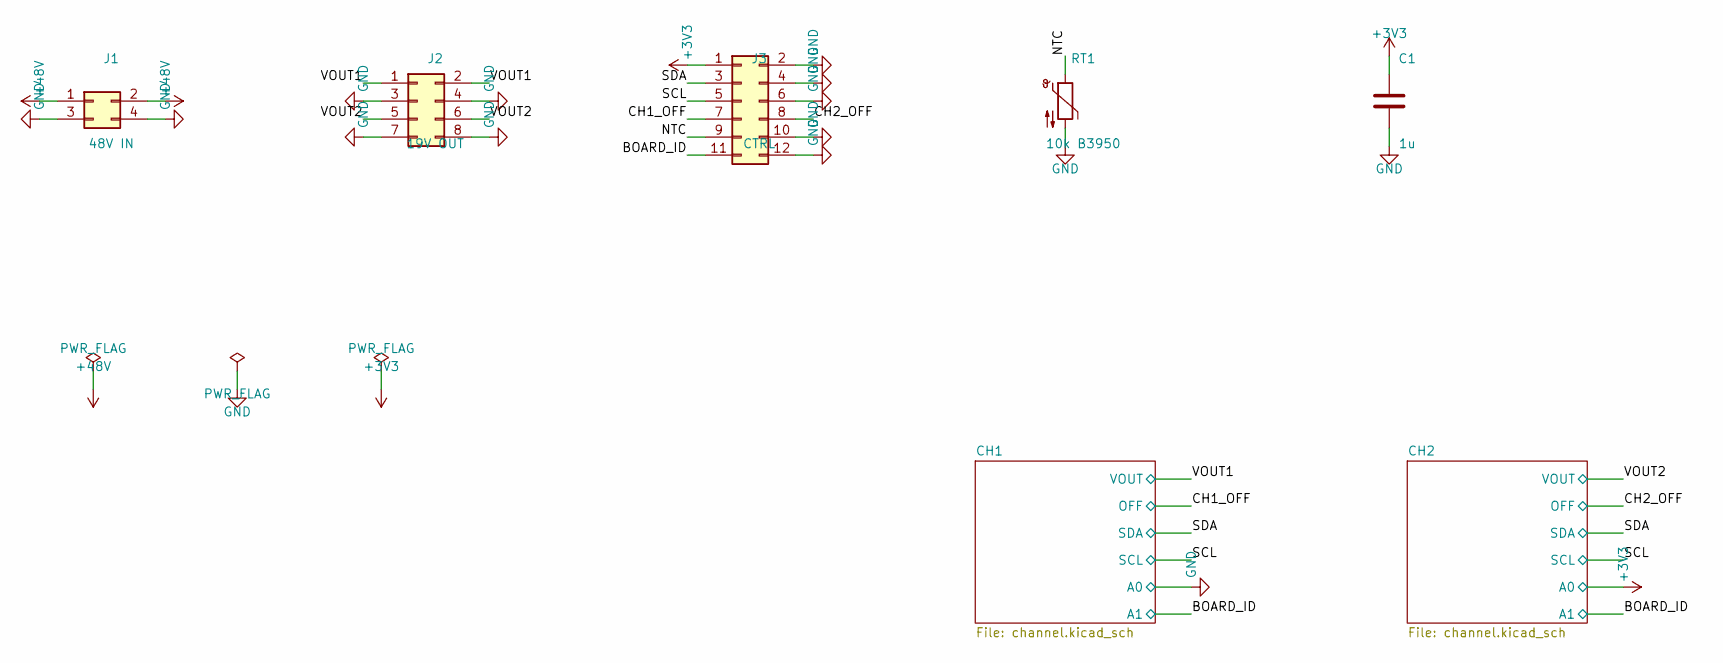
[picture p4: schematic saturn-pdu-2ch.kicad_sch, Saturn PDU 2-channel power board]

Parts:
C1: 1u; C_0603_1608Metric
J1: 48V IN; Molex_Mini-Fit_Jr_5566-04A_2x02_P4.20mm_Vertical; MPN Molex Mini-Fit Jr 5566-04A
J2: 19V OUT; Molex_Mini-Fit_Jr_5566-08A_2x04_P4.20mm_Vertical; MPN Molex Mini-Fit Jr 5566-08A
J3: CTRL; IDC-Header_2x06_P2.54mm_Vertical
RT1: 10k B3950; R_0603_1608Metric; MPN Murata NCP18XH103F03RB

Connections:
+3V3: C1.1, J3.1; also elsewhere on the board
+48V: J1.1, J1.2; also elsewhere on the board
/BOARD_ID: J3.11; also elsewhere on the board
/CH1_OFF: J3.7; also elsewhere on the board
/CH2_OFF: J3.8; also elsewhere on the board
/NTC: J3.9, RT1.1
/SCL: J3.5; also elsewhere on the board
/SDA: J3.3; also elsewhere on the board
/VOUT1: J2.1, J2.2; also elsewhere on the board
/VOUT2: J2.5, J2.6; also elsewhere on the board
GND: C1.2, J1.3, J1.4, J2.3, J2.4, J2.7, J2.8, J3.2, J3.4, J3.6, J3.10, J3.12, RT1.2; also elsewhere on the board

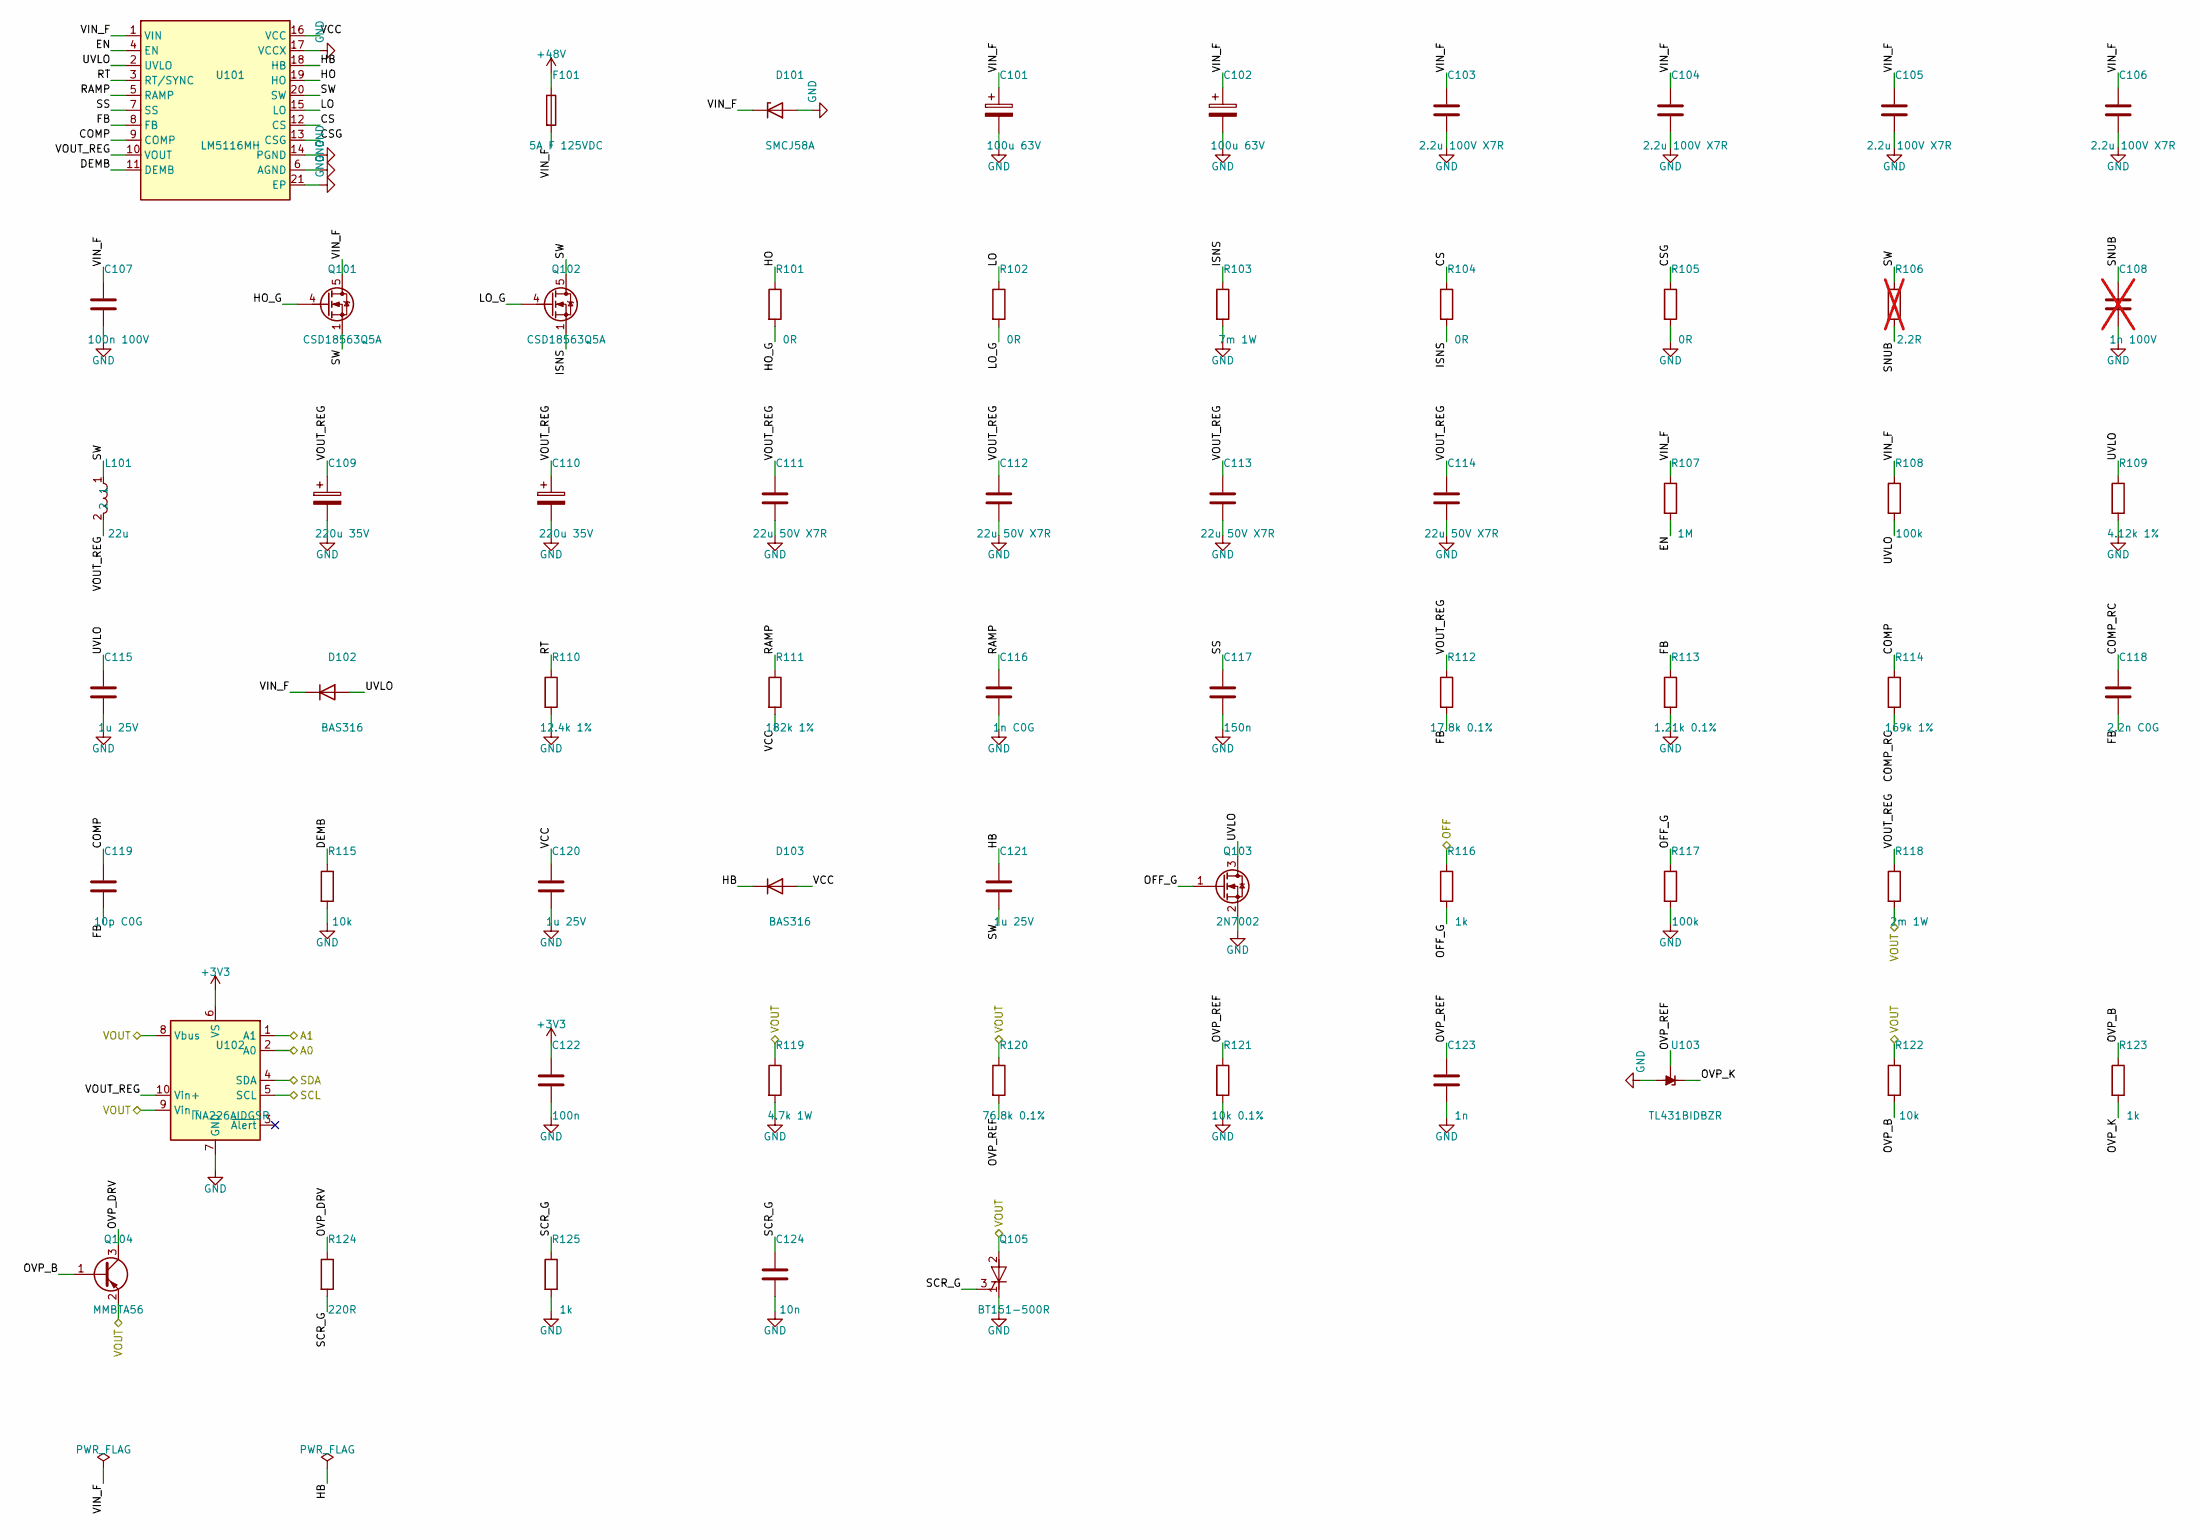
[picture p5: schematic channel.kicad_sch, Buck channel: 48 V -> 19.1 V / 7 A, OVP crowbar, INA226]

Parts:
C101, C102: 100u 63V; CP_Elec_10x10.5; MPN Panasonic EEEFK1J101P
C103, C104, C105, C106: 2.2u 100V X7R; C_1210_3225Metric; MPN Murata GRM32ER72A225KA35L
C107: 100n 100V; C_0805_2012Metric
C108: 1n 100V; C_0805_2012Metric; not fitted
C109, C110: 220u 35V; CP_Elec_8x10; MPN Panasonic EEHZA1V221P
C111, C112, C113, C114: 22u 50V X7R; C_1210_3225Metric; MPN Murata GRM32ER71H226KE15L
C115, C120, C121: 1u 25V; C_0603_1608Metric
C116: 1n C0G; C_0603_1608Metric
C117: 150n; C_0603_1608Metric
C118: 2.2n C0G; C_0603_1608Metric
C119: 10p C0G; C_0603_1608Metric
C122: 100n; C_0603_1608Metric
C123: 1n; C_0603_1608Metric
C124: 10n; C_0603_1608Metric
D101: SMCJ58A; D_SMC; MPN Littelfuse SMCJ58A
D102, D103: BAS316; D_SOD-323
F101: 5A F 125VDC; Fuse_Littelfuse-NANO2-451_453; MPN Littelfuse 0453005.MR
L101: 22u; L_Coilcraft_XAL1510; MPN Coilcraft XAL1510-223MEB
Q101, Q102: CSD18563Q5A; TI_VSONP-8_5x6mm_P1.27mm; MPN CSD18563Q5A
Q103: 2N7002; SOT-23
Q104: MMBTA56; SOT-23
Q105: BT151-500R; TO-220-3_Horizontal_TabDown; MPN WeEn BT151-500R
R101, R102, R104, R105: 0R; R_0603_1608Metric
R103: 7m 1W; R_2512_6332Metric; MPN Bourns CRA2512-FZ-R007ELF
R106: 2.2R; R_1206_3216Metric; not fitted
R107: 1M; R_0603_1608Metric
R108, R117: 100k; R_0603_1608Metric
R109: 4.12k 1%; R_0603_1608Metric
R110: 12.4k 1%; R_0603_1608Metric
R111: 182k 1%; R_0603_1608Metric
R112: 17.8k 0.1%; R_0603_1608Metric
R113: 1.21k 0.1%; R_0603_1608Metric
R114: 169k 1%; R_0603_1608Metric
R115, R122: 10k; R_0603_1608Metric
R116, R123, R125: 1k; R_0603_1608Metric
R118: 2m 1W; R_2512_6332Metric; MPN Vishay WSL2512R0020FEA
R119: 4.7k 1W; R_2512_6332Metric
R120: 76.8k 0.1%; R_0603_1608Metric
R121: 10k 0.1%; R_0603_1608Metric
R124: 220R; R_0805_2012Metric
U101: LM5116MH; ETSSOP-20-1EP_4.4x6.5mm_P0.65mm_EP3x4.2mm; MPN LM5116MHX/NOPB
U102: INA226AIDGSR; TSSOP-10_3x3mm_P0.5mm
U103: TL431BIDBZR; SOT-23

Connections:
+3V3: C122.1, U102.6 (VS); also elsewhere on the board
+48V: F101.1; also elsewhere on the board
/BOARD_ID: U102.1 (A1); also elsewhere on the board
/CH1/COMP: C119.1, R114.1, U101.9 (COMP)
/CH1/COMP_RC: C118.1, R114.2
/CH1/CS: R104.1, U101.12 (CS)
/CH1/CSG: R105.1, U101.13 (CSG)
/CH1/DEMB: R115.1, U101.11 (DEMB)
/CH1/EN: R107.2, U101.4 (EN)
/CH1/FB: C118.2, C119.2, R112.2, R113.1, U101.8 (FB)
/CH1/HB: C121.1, D103.1 (K), U101.18 (HB)
/CH1/HO: R101.1, U101.19 (HO)
/CH1/HO_G: Q101.4 (G), R101.2
/CH1/ISNS: Q102.1 (S), Q102.2 (S), Q102.3 (S), R103.1, R104.2
/CH1/LO: R102.1, U101.15 (LO)
/CH1/LO_G: Q102.4 (G), R102.2
/CH1/OFF_G: Q103.1 (G), R116.2, R117.1
/CH1/OVP_B: Q104.1 (B), R122.2, R123.1
/CH1/OVP_DRV: Q104.3 (C), R124.1
/CH1/OVP_K: R123.2, U103.1 (K)
/CH1/OVP_REF: C123.1, R120.2, R121.1, U103.2 (REF)
/CH1/RAMP: C116.1, R111.1, U101.5 (RAMP)
/CH1/RT: R110.1, U101.3 (RT/SYNC)
/CH1/SCR_G: C124.1, Q105.3 (G), R124.2, R125.1
/CH1/SNUB: C108.1, R106.2
/CH1/SS: C117.1, U101.7 (SS)
/CH1/SW: C121.2, L101.1, Q101.1 (S), Q101.2 (S), Q101.3 (S), Q102.5 (D), R106.1, U101.20 (SW)
/CH1/UVLO: C115.1, D102.2 (A), Q103.3 (D), R108.2, R109.1, U101.2 (UVLO)
/CH1/VCC: C120.1, D103.2 (A), R111.2, U101.16 (VCC)
/CH1/VIN_F: C101.1, C102.1, C103.1, C104.1, C105.1, C106.1, C107.1, D101.1 (K), D102.1 (K), F101.2, Q101.5 (D), R107.1, R108.1, U101.1 (VIN)
/CH1/VOUT_REG: C109.1, C110.1, C111.1, C112.1, C113.1, C114.1, L101.2, R112.1, R118.1, U101.10 (VOUT), U102.10 (Vin+)
/CH1_OFF: R116.1; also elsewhere on the board
/SCL: U102.5 (SCL); also elsewhere on the board
/SDA: U102.4 (SDA); also elsewhere on the board
/VOUT1: Q104.2 (E), Q105.2 (A), R118.2, R119.1, R120.1, R122.1, U102.8 (Vbus), U102.9 (Vin-); also elsewhere on the board
GND: C101.2, C102.2, C103.2, C104.2, C105.2, C106.2, C107.2, C108.2, C109.2, C110.2, C111.2, C112.2, C113.2, C114.2, C115.2, C116.2, C117.2, C120.2, C122.2, C123.2, C124.2, D101.2 (A), Q103.2 (S), Q105.1 (K), R103.2, R105.2, R109.2, R110.2, R113.2, R115.2, R117.2, R119.2, R121.2, R125.2, U101.6 (AGND), U101.14 (PGND), U101.17 (VCCX), U101.21 (EP), U102.2 (A0), U102.7 (GND), U103.3 (A); also elsewhere on the board

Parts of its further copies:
C201, C202: 100u 63V; CP_Elec_10x10.5; MPN Panasonic EEEFK1J101P
C203, C204, C205, C206: 2.2u 100V X7R; C_1210_3225Metric; MPN Murata GRM32ER72A225KA35L
C207: 100n 100V; C_0805_2012Metric
C208: 1n 100V; C_0805_2012Metric; not fitted
C209, C210: 220u 35V; CP_Elec_8x10; MPN Panasonic EEHZA1V221P
C211, C212, C213, C214: 22u 50V X7R; C_1210_3225Metric; MPN Murata GRM32ER71H226KE15L
C215, C220, C221: 1u 25V; C_0603_1608Metric
C216: 1n C0G; C_0603_1608Metric
C217: 150n; C_0603_1608Metric
C218: 2.2n C0G; C_0603_1608Metric
C219: 10p C0G; C_0603_1608Metric
C222: 100n; C_0603_1608Metric
C223: 1n; C_0603_1608Metric
C224: 10n; C_0603_1608Metric
D201: SMCJ58A; D_SMC; MPN Littelfuse SMCJ58A
D202, D203: BAS316; D_SOD-323
F201: 5A F 125VDC; Fuse_Littelfuse-NANO2-451_453; MPN Littelfuse 0453005.MR
L201: 22u; L_Coilcraft_XAL1510; MPN Coilcraft XAL1510-223MEB
Q201, Q202: CSD18563Q5A; TI_VSONP-8_5x6mm_P1.27mm; MPN CSD18563Q5A
Q203: 2N7002; SOT-23
Q204: MMBTA56; SOT-23
Q205: BT151-500R; TO-220-3_Horizontal_TabDown; MPN WeEn BT151-500R
R201, R202, R204, R205: 0R; R_0603_1608Metric
R203: 7m 1W; R_2512_6332Metric; MPN Bourns CRA2512-FZ-R007ELF
R206: 2.2R; R_1206_3216Metric; not fitted
R207: 1M; R_0603_1608Metric
R208, R217: 100k; R_0603_1608Metric
R209: 4.12k 1%; R_0603_1608Metric
R210: 12.4k 1%; R_0603_1608Metric
R211: 182k 1%; R_0603_1608Metric
R212: 17.8k 0.1%; R_0603_1608Metric
R213: 1.21k 0.1%; R_0603_1608Metric
R214: 169k 1%; R_0603_1608Metric
R215, R222: 10k; R_0603_1608Metric
R216, R223, R225: 1k; R_0603_1608Metric
R218: 2m 1W; R_2512_6332Metric; MPN Vishay WSL2512R0020FEA
R219: 4.7k 1W; R_2512_6332Metric
R220: 76.8k 0.1%; R_0603_1608Metric
R221: 10k 0.1%; R_0603_1608Metric
R224: 220R; R_0805_2012Metric
U201: LM5116MH; ETSSOP-20-1EP_4.4x6.5mm_P0.65mm_EP3x4.2mm; MPN LM5116MHX/NOPB
U202: INA226AIDGSR; TSSOP-10_3x3mm_P0.5mm
U203: TL431BIDBZR; SOT-23

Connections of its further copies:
+3V3: C222.1, U202.2 (A0), U202.6 (VS); also elsewhere on the board
+48V: F201.1; also elsewhere on the board
/BOARD_ID: U202.1 (A1); also elsewhere on the board
/CH2/COMP: C219.1, R214.1, U201.9 (COMP)
/CH2/COMP_RC: C218.1, R214.2
/CH2/CS: R204.1, U201.12 (CS)
/CH2/CSG: R205.1, U201.13 (CSG)
/CH2/DEMB: R215.1, U201.11 (DEMB)
/CH2/EN: R207.2, U201.4 (EN)
/CH2/FB: C218.2, C219.2, R212.2, R213.1, U201.8 (FB)
/CH2/HB: C221.1, D203.1 (K), U201.18 (HB)
/CH2/HO: R201.1, U201.19 (HO)
/CH2/HO_G: Q201.4 (G), R201.2
/CH2/ISNS: Q202.1 (S), Q202.2 (S), Q202.3 (S), R203.1, R204.2
/CH2/LO: R202.1, U201.15 (LO)
/CH2/LO_G: Q202.4 (G), R202.2
/CH2/OFF_G: Q203.1 (G), R216.2, R217.1
/CH2/OVP_B: Q204.1 (B), R222.2, R223.1
/CH2/OVP_DRV: Q204.3 (C), R224.1
/CH2/OVP_K: R223.2, U203.1 (K)
/CH2/OVP_REF: C223.1, R220.2, R221.1, U203.2 (REF)
/CH2/RAMP: C216.1, R211.1, U201.5 (RAMP)
/CH2/RT: R210.1, U201.3 (RT/SYNC)
/CH2/SCR_G: C224.1, Q205.3 (G), R224.2, R225.1
/CH2/SNUB: C208.1, R206.2
/CH2/SS: C217.1, U201.7 (SS)
/CH2/SW: C221.2, L201.1, Q201.1 (S), Q201.2 (S), Q201.3 (S), Q202.5 (D), R206.1, U201.20 (SW)
/CH2/UVLO: C215.1, D202.2 (A), Q203.3 (D), R208.2, R209.1, U201.2 (UVLO)
/CH2/VCC: C220.1, D203.2 (A), R211.2, U201.16 (VCC)
/CH2/VIN_F: C201.1, C202.1, C203.1, C204.1, C205.1, C206.1, C207.1, D201.1 (K), D202.1 (K), F201.2, Q201.5 (D), R207.1, R208.1, U201.1 (VIN)
/CH2/VOUT_REG: C209.1, C210.1, C211.1, C212.1, C213.1, C214.1, L201.2, R212.1, R218.1, U201.10 (VOUT), U202.10 (Vin+)
/CH2_OFF: R216.1; also elsewhere on the board
/SCL: U202.5 (SCL); also elsewhere on the board
/SDA: U202.4 (SDA); also elsewhere on the board
/VOUT2: Q204.2 (E), Q205.2 (A), R218.2, R219.1, R220.1, R222.1, U202.8 (Vbus), U202.9 (Vin-); also elsewhere on the board
GND: C201.2, C202.2, C203.2, C204.2, C205.2, C206.2, C207.2, C208.2, C209.2, C210.2, C211.2, C212.2, C213.2, C214.2, C215.2, C216.2, C217.2, C220.2, C222.2, C223.2, C224.2, D201.2 (A), Q203.2 (S), Q205.1 (K), R203.2, R205.2, R209.2, R210.2, R213.2, R215.2, R217.2, R219.2, R221.2, R225.2, U201.6 (AGND), U201.14 (PGND), U201.17 (VCCX), U201.21 (EP), U202.7 (GND), U203.3 (A); also elsewhere on the board

Board: 4 copper layers, 133 parts (0 on the bottom side), 67 nets, no tracks yet.

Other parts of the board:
H1, H2, H3, H4: MountingHole_3.2mm_M3

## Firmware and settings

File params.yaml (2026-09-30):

# =============================================================================
# saturn-pdu / params.yaml
# -----------------------------------------------------------------------------
# SINGLE SOURCE OF TRUTH for every dimension, rating and threshold that appears
# in more than one place. Documentation, ESPHome firmware and the FreeCAD
# scripts all read from this file. Change a value here, not in three places.
#
# Values marked PROVISIONAL are placeholders standing in for a measurement that
# has not been taken yet. Each carries the OPEN-n item it belongs to. They are
# tracked as GitHub issues and are re-checked as gates at WP-8 (before anything
# is ordered) -- see docs/SPECIFICATION.md section 11.1.
#
# Licence: CERN-OHL-S v2. See LICENSE and NOTICE.
# =============================================================================

meta:
  project: saturn-pdu
  spec_version: "0.1"
  spec_status: draft-pre-review     # nothing here has been built or bench-verified
  license: CERN-OHL-S-2.0

# -----------------------------------------------------------------------------
# The load: six Minisforum MS-01 nodes
# -----------------------------------------------------------------------------
load:
  node_model: Minisforum MS-01
  node_count: 6
  input_voltage_v: 19.0
  # Nameplate is the stock brick (Huntkey HKA18019095-6C). The design is NOT
  # sized to this -- see power_budget. Recorded for reference only.
  nameplate_v: 19.0
  nameplate_a: 9.47
  nameplate_w: 180

# -----------------------------------------------------------------------------
# OPEN-5 -- output connector. Gates the rear panel cutout and the jack part No.
#
# Why this is safe to defer: 5.5x2.5mm and 5.5x2.1mm barrel jacks share the same
# 8mm panel-mount thread, so panel_thread_mm (the only value the CAD needs) is
# NOT provisional. Only the purchased part number depends on the measurement.
# Risk if the placeholder is wrong: one incorrect ~$2 part.
#
# To close: measure the stock MS-01 plug with calipers -> update the three
# PROVISIONAL values below -> confirm the jack part number at WP-8.
# -----------------------------------------------------------------------------
output_connector:
  type: barrel_jack
  outer_diameter_mm: 5.5          # PROVISIONAL (OPEN-5)
  inner_diameter_mm: 2.5          # PROVISIONAL (OPEN-5) -- 2.1 is the other candidate
  polarity: centre_positive       # PROVISIONAL (OPEN-5)
  panel_thread_mm: 8.0            # NOT provisional -- identical for both candidates
  current_rating_a: 8             # RESOLVED (OPEN-8). Kycon KLDHCX-8-0202-B.
  locking: false                  # CHANGED 2026-09-30: user decision, locking not required.
                                  # See docs/safety.md S2 for what this costs.

  # OPEN-8 RESOLVED 2026-09-30.
  #
  # WP-3 sourcing found NO panel-mount 5.5x2.5mm barrel jack rated above 5A from
  # any manufacturer -- Same Sky's entire panel-mount line tops out at 5.0A. With
  # the locking requirement dropped, the constraint reduced to "5.5x2.5mm, >=7A",
  # and that DOES exist as a right-angle through-hole part:
  part: Kycon KLDHCX-8-0202-B
  mounting: pcb_right_angle        # NOT panel mount -- see note below
  distributor: Mouser 5196 in stock / DigiKey 104
  price_qty10_usd: 1.81
  voltage_rating_v: 24             # 19V output: 26% margin
  #
  # MOUNTING CONSEQUENCE: this is a right-angle THT jack, so it cannot bolt to the
  # rear panel directly. It goes on a small 2-layer "output board" behind the panel
  # carrying all six jacks, with the barrels protruding through six clearance holes.
  # That board is also the natural home for the output TVS and bleed resistors.
  # Added to the BOM as assembly OUT.
  #
  # MARGIN: 8A rated against 6.05A turbo peak (32%) and ~5A sustained (60%).
  # The 7A figure in E-2 is the CHANNEL's capability, not the load.

# Interconnect: PDU rear jack -> MS-01 DC input. Six required.
# The stock Huntkey brick's cable is CAPTIVE, so it cannot be reused: these are
# new leads with a barrel plug at BOTH ends.
interconnect_cable:
  count: 6
  length_mm: 500
  conductor_awg: 18               # NOT a guess: at 7A over a 0.5m run (1m round trip)
                                  # 18AWG drops ~0.15V / ~1.0W. 22AWG -- what most cheap
                                  # DC extension leads actually are -- drops ~0.37V / ~2.6W.
                                  # Specify the gauge; do not buy on price.
  voltage_drop_v: 0.15            # at 18AWG, 0.5m, 7A
  both_ends_locking: false        # only the PDU end can lock; the MS-01 jack is friction-fit
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

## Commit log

2026-09-30 feat: fork HomeLab-PDU-V1 as saturn-pdu, scaffold repository
    Establish saturn-pdu as a CERN-OHL-S v2 derivative targeting six 19V
    outputs for MS-01 nodes, replacing upstream's 5x USB-C PD architecture.
    The MS-01 cannot be powered over USB-C, so upstream's entire power path
    is discarded. What is inherited is the mechanical architecture and the
    per-channel fuse/TVS/bulk-cap protection pattern.
    Removed: 10in chassis variants, USB-C PD assets, upstream gerbers and
    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
    [10in_3D-Back-FLIPPED.STL, 10in_3D-Back.STEP, 10in_3D-Back.stl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]
2026-09-30 docs: full documentation set (WP-2)
    - SPECIFICATION.md: the design spec, amended from the approved plan with
    P-12 (unconnected-output alert), M-7 (locking jacks), and a new 4.8.1
    covering the interconnect cable and the live-plug question.
    - power-budget.md: load characterisation, 48V rail loading, the RSP-1000
    upgrade path, and the 1x750W vs 2x450W decision record.
    - thermal.md: dissipation budget, airflow, where the heat physically is,
    and why the integrated-FET route failed on package thermals (207-252C
    junction) forcing the discrete route.
    - protection.md: layered protection, crowbar/fuse coordination, and a
    16-row FMEA. Read as a whole it says rows 1 and 2 are the entire risk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
2026-09-30 fix(psu): RSP-750-48 is discontinued — fit RSP-1000-48
    Sourcing at WP-3 found the specified PSU end-of-life. Three units compared
    (RSP-750-48 / RSP-1000-48 / UHP-750-48); the RSP-1000-48 was selected.
    The change costs nothing structurally: the chassis and 48V bus were already
    dimensioned to its 295x127x41mm envelope under M-2, because it had been
    specified as the upgrade path. The upgrade path became the build.
    Consequences:
    - R-3 (750W proves marginal) CLOSED. 726W peak is 72% of rating, not 96%.
    - OPEN-6 (six-node peak measurement) downgraded from hard gate to
    informational. The design now absorbs a reading 38% above estimate.
    - Crowbar/fuse coordination improved: 21A constant-curren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
    [params.yaml]
2026-09-30 feat(fab): WP-3 BOM and live sourcing
    fab/bom.csv: 44 lines across 2CH / CTRL / DISP / BP / CHASSIS / SERVICE /
    TOOLING, with a verified column marking which prices were looked up live
    (13 critical-path lines) versus catalogue estimates.
    Sourcing found three things the spec had wrong:
    1. PSMN5R2-60YS does not exist. The real Nexperia part is PSMN5R5-60YS and
    it is out of stock at LCSC. Substituted Infineon BSC0702LS (D-8): lower
    Rds(on) (2.7 vs 5.2 mOhm), lower Qg, cheaper, 8427 in stock, and
    characterised at Vgs=4.5V so its worst case at the LM5116's 7.4V gate
    drive is bounded rather than guessed. Loss budget updated.
    2. The XAL1510-223's "18.7A / 14.5 mOhm" and the distribut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
    [bom.csv]
2026-09-30 fix(connector): OPEN-8 resolved — locking dropped, Kycon KLDHCX-8-0202-B fitted
    User decision: locking is not required. That reduced the requirement from
    "panel-mount, locking, 5.5x2.5mm, >=7A" (which does not exist) to
    "5.5x2.5mm, >=7A" (which does).
    Fitted Kycon KLDHCX-8-0202-B: 8A / 24VDC, $1.81@10, 5196 in stock at
    Mouser. 32% margin on the 6.05A turbo peak, 63% on the ~5A sustained draw.
    It is right-angle through-hole, not panel mount, and that is the reason it
    is rated 8A rather than 5A: every panel-mount jack in this barrel size
    tops out at 5.0A because the rating is set by the termination. Consequence
    is a new small 2-layer output board behind the rear panel carrying all six
    jack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
    [bom.csv]
2026-09-30 WP-4a: project KiCad libraries, with a BOM correction
    Symbols and footprints for the 2-channel power board. The rule followed is
    "author only what KiCad 10.0.0 does not already ship, and record which stock
    item was chosen for everything else and what it was checked against" — with no
    external review (R-0), the written record is the review.
    Authored, because KiCad ships no equivalent:
    - saturn-pdu:LM5116 — 21 pins from TI SNVS499I Table 4-1. SW and CSG are typed
    passive rather than output/ground so ERC reports real errors instead of
    structural noise; both departures are documented.
    - saturn-pdu:L_XAL1510-223MEB and saturn-pdu:L_Coilcraft_XAL1510 — land pattern
    from Coilcraft Doc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
    [bom.csv]
2026-09-30 WP-4b: replace BSC0702LS with CSD18563Q5A (LM5116 start-up limit)
    The LM5116 VCC regulator is guaranteed to only 15 mA and must supply
    (Qg_HS + Qg_LS) x fsw. The BSC0702LS pair draws ~17 mA at 250 kHz and
    7.4 V drive, so start-up is not guaranteed. The CSD18563Q5A draws
    ~7.5 mA per pair.
    - Add saturn-pdu:TI_VSONP-8_5x6mm_P1.27mm: KiCad's VSONP-8 footprint
    renumbered to match the CSD18563Q5A symbol (1-3 S, 4 G, 5 D). The
    stock TDSON-8-1 default does not match TI's land pattern.
    - BOM, cost totals, D-10 (supersedes D-8), spec, sourcing notes and
    library README updated. INA226 footprint confirmed as TI DGS0010A.
    [bom.csv]
2026-09-30 WP-4b: keep 60V FETs; add switch-node spike bench gate and PSU trim lock
2026-09-30 WP-4b: 2-channel power board schematic (ERC-clean)
    - hardware/kicad/saturn-pdu-2ch: hierarchical schematic, top sheet with
    J1 (48V Mini-Fit 2x2), J2 (outputs Mini-Fit 2x4), J3 (2x6 signal header),
    NTC and two instances of channel.kicad_sch (LM5116 buck, OVP crowbar,
    INA226 telemetry, fail-ON remote disable).
    - kicad-cli sch erc: 0 errors, 0 warnings. Exported netlist checked pin by
    pin against the generator's intended connections: 0 mismatches.
    - tools/gen_2ch_sch.py is one-shot: do not re-run after hand edits.
    - BOM: schematic refs, new connector rows, MMBTA56 OVP PNP, BAS316,
    2N7002 moved from CTRL to 2CH, DNP snubber row.
    - deviations D-11..D-14 (connectors/harness, OVP PNP driv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
    [bom.csv, channel.kicad_sch, saturn-pdu-2ch.kicad_sch]
2026-09-30 WP-4c: 2-channel board setup; correct two upstream-analysis errors
    Board (hardware/kicad/saturn-pdu-2ch):
    - 90x130mm outline (upstream's, read from its .kicad_pcb), 4x M3 holes
    - 4-layer 2oz/1oz 1.62mm stackup, In1 GND plane
    - net classes HV / POWER / GATE, JLC 2oz minimums, custom rules for 48V
    spacing and switch-node keep-away (.kicad_dru)
    - all 129 parts loaded with nets and schematic links, packed per channel
    in functional order and grouped CH1/CH2
    - DRC: 0 schematic-parity issues; only unrouted connections and silk
    overlaps remain (routing is WP-4d)
    - README.md: layout checklist for WP-4d
    Corrections:
    - Upstream DID publish editable source: KiCad project and SolidWorks
    parts we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
    [saturn-pdu-2ch.kicad_pcb]
2026-09-30 Ignore KiCad 10 local history directories

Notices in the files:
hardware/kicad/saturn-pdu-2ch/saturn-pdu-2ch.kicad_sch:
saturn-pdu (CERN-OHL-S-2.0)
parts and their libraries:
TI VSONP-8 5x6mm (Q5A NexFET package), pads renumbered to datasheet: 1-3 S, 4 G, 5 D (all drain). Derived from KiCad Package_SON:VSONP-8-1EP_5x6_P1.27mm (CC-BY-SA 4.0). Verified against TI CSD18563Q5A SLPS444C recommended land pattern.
